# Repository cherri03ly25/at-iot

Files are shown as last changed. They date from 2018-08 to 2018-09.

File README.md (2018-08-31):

# BLE Sensor Board and Web Interface

This project defines a sensor board that broadcasts information to an IoT gateway, which then pushes the data to Azure IoT Hub. The data is then transferred to a node.js webserver that then broadcasts it to browser clients.

## Contents

* KiCAD schematics and PCB design for an nRF52840-powered sensor board
* source code for the nRF52840, required for it to send data to an IoT gateway utilizing BLE beacons
* source code for a node.js webserver capable of receiving data from Azure IoT Hub and broadcasting it to the users of a website
* the documentation for all of the above, instructions

## Installation Instructions

All parts of this project (webserver, firmware and KiCAD schematics) come with installation instructions. They can be found in their respective directories, in the INSTALL file.

## Licensing

See LICENSE.

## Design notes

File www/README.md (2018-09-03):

# Web Interface

## Supported Browsers

Browser | Version
-------:|:------
Mozilla Firefox | 60.0+
Google Chrome | 67.0+
Safari | 11.0+
Microsoft Edge | N/A

## Installation Instructions

Due to the short amount of time available for this project, server installation is only documented for linux machines with the Aptitude package manager installed.

### Steps

1. Install node.js, and optionally npm and pm2.
2. Install socket.io and express. (This can be done by running `npm install` in `./node.js` if npm was installed)
3. Tweak `node.js/config.json` to your liking.
4. Run server with `node node.js/index.js` or `pm2 start node.js/index.js`
5. Navigate to [http://localhost:3000/atsb] if using the default settings.

### Dependencies

Dependency | Required | Recommended | Version | Install Command
----------:|:--------:|:-----------:|:-------:|:----------------
`node.js` 	| x | x | v8.10.0 	| `sudo apt install nodejs`
`npm` 		|   | x | 3.5.2 	| `sudo apt install npm`
`pm2` 		|   | x | 2.10.4 	| `sudo npm install -g pm2`
`socket.io` 	| x | x | 2.1.1 	| `npm install socket.io`
`express`	| x | x | 4.16.3 | `npm install express`

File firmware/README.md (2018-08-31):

After cloning the git the submodules need to be updated using the command: 
'git submodule update --init'
to get the necessary sensor APIs.
### Packet Format
| Field | Size (in bytes) | Fixed Value | Description |
|:-----:|:----:|:---:|:---:|
| **Fixed Header** |
| Length | 1 | 0x1E |
| Type | 1 | 0xFF |
| Company ID | 2 | 0xFFFF | Bluetooth company ID |
| **Payload** |
| CTR | 4 | | Incrementing counter to improve security
| DATA1 | 4 | | The data
| TYP1 | 2 | | The data type
| DATA2 | 4 | | The data
| TYP2 | 2 | | The data type
| HASH | 11 | | A hash of the encrypted data
												
* modified to have max 27 bytes of user payload
* modified sdk_config.h and Makefile to run ble-twi-aes
* created encrypt.h and encrypt.c for data encryption
* created drivers for AES,I2C,BME280,APDS9960,sensors.h etc.
* refactoring
											
### Update:
* run beacon at low power mode
* added radio_notification SWI interrupt (need removing nrf_error.h in  sdk/components/drivers_nrf/nrf_soc_nosd)
* modified payload
* successfully uploaded codes to the custom board
* extract and give the path to sdk in Makefile
* replace Makefile.posix in sdk/components/toolchain/gcc with one in config/
* Jlink debugging at different terminals:

$ JLinkExe -if swd -device nrf52 -AutoConnect 1 -speed 4000

$ JLinkRTTClient

### Instructions of setting up development environment:

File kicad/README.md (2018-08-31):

# README

## Prerequisites

To view or edit pcb design files you need to use KiCad v5.0 program. 

Required libraries you can get from SnapEDA: https://www.snapeda.com/

Needed parts:

* Rigado BMD-340
* LP5907MFX-3.3_NOPB
* BMI055
* APDS-9960 

## Installing KiCAD
 
You can get KiCad for your operating system from http://kicad-pcb.org/ website.

1. Install KiCAD
2. Run KiCAD
3. Use recommended library settings
4. Get project from GitHub
5. Open .pro file from project folder with KiCAD
6. Now you can modify schema/layout with eeschema/pcbnew
7. To import symbol libraries go in Eeschema to "Preferences->Manage Symbol Libraries" and add.
8. To import footprint libraries go in Pcbnew to "Preferences->Manage Footprint Libraries" and add.

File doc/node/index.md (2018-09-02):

# Data Aggregation Server

## Installation

Refer to the [README](../../www/node.js/README.md)
for the installation instructions.

## Data Format

After parsing the data, the server stores a single reading as an object
in the below format.
Additional properties may be added.

        {
            id: "<sensor id>@<device mac>",
            value: <number>,
            time: <ms since epoch>
        }

## Command Line Interface

*This section details features that are not yet fully implemented.*

The server CLI can be enabled by calling `atsb.cliEnabled(true)`
in the server code. The included example has the CLI enabled
by default. Run `help` in the CLI for more information
about the available commands.

## Server-Side Events

The server emits a variety of events that can be caught by using `atsb.on(event, callback)`.
Below, a variety of events emitted by the server are detailed, along with when and where
the events are emitted, and what arguments they pass to the callback.

Event 		| Emitted by  | Arguments | Description 
:-----------|:------------|:----------|:----------------
`Info` 		| all modules | type, str, ...args | See below.
`Warning`	| all modules | type, str, ...args | See below.
`Error`		| all modules | type, str, ...args | See below.

The next few sections detail the various types of `Info`, `Warning` and `Error`
events. It should be noted that the `type` and `str` arguments are omitted in
those sections to reduce redundancy, but they *will* be passed to any callback
listening to any of the three events.

### Info Events

Emitted when the server does something of potential interest, e.g. adds a new device.
The `type` argument is a short name for what happened, and the following `str` gives
a more detailed account, suitable for logging.

Type | Emitted by | Arguments | Description
:----|:-----------|:----------|:------------------
`ClientConnected` | `atsb.js` | socket, user | Emitted when a user connects to the server. `user` is an object describing their credentials and permissions.
`ClientDisconnected` | `atsb.js` | socket, user | Emitted when a user disconnects. Otherwise same as `ClientConnected`.
`DeviceAdded` | `device.js` | device | Emitted when the server registers a new device.
`DeviceUpdated` | `device.js` | device, propertyName, propertyValue | Emitted when the server changes device information - e.g. adds new sensors, or changes the name.
`MessageParsed` | `atsb.js` | msgId, nParsed | Emitted when the server parses a message from a beacon. `msgId` is an 8-character identifier to help tracking messages, and `nParsed` is the number of readings parsed from the message.
`PostReceived` | `atsb.js` | msgId | Emitted when the server receives a POST request
`StreamedData` | `atsb.js` | msgId | Emitted when the server streams the data from a POST request

### Warning Events

Emitted when the server does something that potentially requires attention.
The `type` argument is a short name for what happened, and the following `str` gives
a more detailed account, suitable for logging.

Type | Emitted by | Arguments | Description
:----|:-----------|:----------|:------------------
`CounterValidationWarning` | `parser.js` | msgId, mac, msg | Emitted when a message with an invalid counter is received.
`HMACValidationWarning` | `parser.js` | msgId, mac, msg | Emitted if HMAC validation fails.
`NoParserOutputWarning` | `atsb.js` | msgId, msg, parser | Emitted if a parser produces no output.
`UnknownDeviceWarning` | `parser.js` | msgId, mac, msg | Emitted if data was received from an unknown device.
`UserAuthWarning` | `atsb.js` | socket, user | Emitted when a user lacks the permissions to view the stream.

### Error Events

Emitted when the server does something that almost certainly requires attention.
The `type` argument is a short name for what happened, and the following `str` gives
a more detailed account, suitable for logging.

Type | Emitted by | Arguments | Description
:----|:-----------|:----------|:------------------
`ParserNotFoundError` | `atsb.js` | msgId, msg | Emitted if no parser was found for the message.

## Client-Side Events

If desired, the visualization client may be rewritten. This can be done by
connecting to the appropriate Socket.IO namespace, and by handling and emitting 
the events described below. If the event is not marked as 'Implemented', it is
not yet supported by the server.

Upon connecting to the server, the client receives an object describing its
permissions. Refer to the [Permissions Module](./permissions.md) for more information.
The client can choose to ignore these, but the server will enforce them.

### Events Emitted by Server

Event | Implemented | Arguments | Description
:----|:----------|:----------|:------------------
`Data`  | x | data | Data. Either a single data point, or an `Array`. The data matches the [Data Format](#data-format)
`DeviceAdded`| x | devInfo | Emitted when the server registers a new device. `devInfo` is an object describing the device.
`DeviceList` | x | devInfoList | Emitted upon list request or when connecting to the server. `devInfoList` contains all device info objects.
`DeviceUpdated` | x | devInfo | Emitted when the server updates a device. `devInfo` is the updated device description.

### Events Emitted by Client

Event | Implemented | Arguments | Description
:----|:----------|:----------|:------------------
`ListDevices` | x | Used to request the list of devices.
`Subscribe` | x | rooms | `rooms` should be an `Array` of sensor identifiers. This event indicates to the server that the client wants the associated data.
`Unsubscribe` | x | rooms | This event can be used to undo `Subscribe`.
`RequestData` | | requests | Used to request data from a certain interval and sensor from the server. `requests` is an `Array` of objects: `{id:<sensor id>, start:<time1>, end:<time2>}`
`ChangeDevice`| | mac, property, value | Used to update a property of a device, e.g. rename it or edit its key.
`AddDevice` | | mac, key, name | Used to create a new device.

## Customizing the Server

There are two primary methods to customizing the server to suit
your needs: editing the JSON configs or by overriding functions or modules.

### config.json

*Some of the features described in this section are not fully described.*

Options available are:

Option | Values | Default | Description
:------|:-------|:-----------------
`urlPrefix` | String | "/atsb" | Sets the prefix to all related URLs, including the endpoints and static files.
`urlEndpoint` | String | "/endpoint/webhook" | Sets the endpoint. To use URL authentication, include `:auth` in the URL.
`namespace` | String | "atsb" | The name of the Socket.IO namespace.
`defaultParser` | String, `null` | "./parser.js" | The name of the parser to load on initialization. Set to `null` for none.
`logging` | | | Various options for logging
`logging.enabled` | boolean | `true` | Enable or disable logging
`logging.events` | Array | `["Warning", "Error"]` | A list of all the events to log. "All" for all events, "Info", "Warning" or "Error" for all events of that category.
`logging.prefix` | String | "\[ATSB\] <$TIME> $TYPE: " | A prefix to prepend to all logged events. '$TIME' is replaced with current time (hh:mm:ss) and '$TYPE' with the event type.
`logging.postfix` | String | "" | A postfix to append to logged events. Works like `logging.prefix`.
`storage` | | | Various options for the default storage module
`storage.prefix` | String | "$DIRNAME/var/atsb" | A prefix to append to all file paths (except config). '$DIRNAME' is replaced with the `__dirname` variable.
`storage.data` | String | "/data/$YYYY/$MM/$DD/$hh$mm" | The file(s) to store collected data in. The variables ($YYYY, $MM, etc.) are replaced with the appropriate time from the data timestamp(s).
`storage.exitSave` | boolean | `true` | Whether the server should save changed configurations on exit. If disabled, calling `atsb.save()` does the same.
`storage.devices` | String | "devices.json" | The file to store device configurations in.
`storage.sensors` | String | "sensors.json" | The file to store sensor configurations in for the default parser.
`storage.users` | String | "users.json" | The file to store users, their permissions and login credentials in.
`storage.compression` | boolean | `true` | Whether files should be compressed.
`storage.encryption` | | | Various options for encrypting files
`storage.encryption.enabled` | boolean | true | Whether to encrypt/decrypt files.
`storage.encryption.keyMethod` | String | "stdin" | How to retrieve the key. "stdin" queries the key from `stdin` on startup, "config" requires the key to be defined in the config file (very insecure!), "file" retrieves the key from a file (equally insecure).
`storage.encryption.key` | String, `null` | `null` | If `storage.encryption.keyMethod` is set to "config", this option sets the key. It should be a hex-encoded string.
`storage.encryption.algorithm` | String | "aes-256" | The encryption algorithm for the module. Must be supported by the `crypto` module.

### Storage

The API for the storage module is not yet done, so this section is left empty

### Custom Parsers

The server software supports addition of new parsers for user-defined protocols.
This is done by creating a new object that has the public member functions 
`canParse()` and `parse()` defined as below. If desired, the parser may also
implement the `info()` function.

If desired, the default parser can be disabled by setting `defaultParser` in
`config.json` to `null`, or replaced by setting it to refer to a new file
(not recommended).

#### canParse(msg)

* The function must take a single argument, the message.
* It must determine whether the message is a valid input for `parse()`
* It must return `true` if the message is valid input, and `false` otherwise

#### parse(msg, msgId)

* The function is passed two arguments: the message, and the message identifier.
* It must parse the message, and return an `Array` containing data objects. 
* The parsed data objects *must* follow the [Data Format](#data-format).
* The function should return an empty set (`[]`) if the message contained no readings.
* The function should return `null` if the parser failed due to invalid message.
* The function *may* call `update()` on the associated `Device`(s)
* The function *may* call `log()` on the associated `Device`(s).
The default parser logs the following statistics: 
`AllMessages`, `ValidMessages`, `SkippedMessages`, `InvalidCTRs`, `InvalidHMACs`
* The `msgId` parameter can safely be ignored
* The implementation can safely assume that `canParse()` returned
true for the message.

#### info(...args)

*This section details features that are not made use of in the current version*

* The function is called when the user uses the `parser info <parser>` command.
* Any arguments after `<parser>` are passed to the function.
* The function should return either an `Array` of `string`s or a `string`.
* The return value is printed in console.
* If the returned value was an `Array`, `join("\n")` is called on it first.

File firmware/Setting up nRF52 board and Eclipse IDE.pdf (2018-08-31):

## Setting up development environment

Notes: executable files can be installed graphically or by command lines

### 1. GNU make

$ sudo apt install build-essential checkinstall

### 2. GNU toolchain for ARM Cortex-M

Download and install the GNU ARM Toolchain package for linux-64 (https://developer.arm.com/open-source/gnu-toolchain/gnu-rm/downloads) $ sudo apt install unzip
$ tar xf gcc-arm-none-eabi-7-2017-q4-major-linux.tar.bz2
// may need gcc_multilib
$ sudo apt install gcc-multilib
// add the location to the path temporarily when executing locally in a terminal:
$ export PATH=$PATH: $(HOME)/.../.../gcc-arm-none-eabi-7-2017-q4-major/bin $ echo $PATH

### 3. SEGGER J_Link

Download and install the Segger JLink package for linux-DEB-64 (https://www.segger.com/downloads/jlink/#J-LinkSoftwareAndDocumentationPack)
$ sudo dpkg -i JLink_Linux_V632g_x86_64.deb //check exe file "jlink*" under usr/bin

### 4. nRF5_SDK

Download and unzip the nRF52-SDK zip package (http://infocenter.nordicsemi.com/index.jsp)
//To do make, need to source GNU ARM
nRF52_SDK >>components >> toolchain >> gcc >> Makefile.posix
GNU_INSTALL_ROOT := $(HOME)/.../.../gcc-arm-none-eabi-7-2017-q4-major/bin/ yGNU_VERSION := 7.2.1
GNU_PREFIX := arm-none-eabi

### 5. nRF5x-Command-Line-Tools

Download the nRF5x Tools Linux64 (https://www.nordicsemi.com/eng/nordic/Products/nRF52840/nRF5x-Command-Line-Tools-Linux64/58852) (see p.10) (http://www.farnell.com/datasheets/2577979.pdf) $ gedit ~/.bashrc
export PATH=$PATH:~/.../.../nRF5x-Command-Line-Tools/nrfjprog export PATH=$PATH:~/.../.../nRF5x-Command-Line-Tools/mergehex

### 6. Reset MCU interface

JLINK interface is set as default interface for the dev kit and chosen to be used in this project. Other MCU interface can be used, for example DAPLINK interface.
JLINK interface: Download .bin file for JLINK interface software (http://www.nordicsemi.com/eng/nordic/Products/nRF52-DK/nRF5x-OB-JLink-IF/52275) from: http://www.nordicsemi.com/eng/Products/nRF52840-DK#Downloads
DAPLINK interface: Download .bin file for DAPLINK interface software (https://armmbed.github.io/DAPLink/?board=Nordic-nRF52-DK) from os.mbed.com (https://os.mbed.com/platforms/Nordic-nRF52840-DK/)

- Press boot/reset button while turning power switch from OFF to ON -> BOOTLOADER mode
- Copy the downloaded .bin file into devboard and wait until LED5 fast flashing
- Press boot/reset button while turning power switch from OFF to ON -> MCU interface (JLINK/DAPLINK etc.) is reset.

### 7. Run demo with GCC and command tools (JLink interface)

Change directory to ~/.../.../sdk/examples/peripheral/blinky/pca10056/blank/armgcc/
//do make, _build folder is created
$ make

/*1. run with nrfjprog*/
//erase target
$ nrfjprog --family nRF52 -e
//load FW image to target
$ nrfjprog --family nRF52 --program _build/nrf52840_xxaa.hex //reset and run
$ nrfjprog --family nRF52 -r

/*2. run with JLinkExe*/
/* Open Jlink Commander from terminal in _build directory */ JLinkExe -device <nRF51/nRF52>
> erase // Optional: erase target if not already blank
> loadfile <name>.hex // loads FW
> r // Reset and halt
> g // Run
> q // Exit

/*3. directly copy example .hex file into target via USB*/

### 8. Program target with os.mbed.com/compiler

- Target device: nRF52-DK
- Import demo project nRF52840-Preview-DK-blinky
- Use mbed.h library for high level programming
- Code and compile to create application .hex file
- Copy the .hex file to the target and wait until the JLINK/DAPLINK interface disappears and reappears
- Press boot/reset button to start running the application
Good reference -> import BLE project: mbed-os-example-client-BLE-NRF52_DK (https://github.com/andcor02/mbed-os-NRF52_DK-Gateway)

### 9. Setting up Eclipse IDE

***Download and install Eclipse***

- Download and unzip eclipse package (newest version of Eclipse Oxygen linux 64 bit): http://www.eclipse.org/downloads/
- Double click on "eclipse-inst" exe file >> Eclipse IDE for C/C++ Developers >> choose directory for installation
- Double click on "eclipse" exe file >> choose directory for workspace
- Source exe file:
$ gedit ~/.bashrc
export PATH=$PATH:~/.../.../eclipse

***I nstall GNU MCU eclipse plug in*** (https://gnu-mcu-eclipse.github.io/plugins/install/)
Open eclipse in terminal or by double click on the exe file >> Help >> Eclipse Marketplace >> Find and install GNU MCU Eclipse
Required packages are:
GNU ARM C/C++ Cross Compiler
GNU ARM C/C++ Packs
GNU ARM C/C++ J-link Debugging
All packages are chosen by default.

***Install device family pack for the nRF5x serie***
Window >> Perspective >> Open Perspective >> Other >> Packs >> Open.
Click the refresh button to fetch all packs from the repositories.
Select Nordic Semiconductor in the list of vendors, and install the latest version of Device family pack. (Skip if all invalid packages!)

***Create a project***
Common Settings:
- Window >> Preference >> MCU
- >> Global ARM Toolchains Paths >> Default toolchain: GNU Tools for ARM Embedded Processors >> Build tools folder: ~/.../.../gcc-arm-none-eabi-7-2017-q4-major/bin
- >> Global Build Tools Path >> Build tools folder: ~/nRF5x-Command-Line-Tools/nrfjprog
- >> Global SEGGER J-Link Path >> Executable: JLinkGDBServerCLExe >> Folder: /opt/SEGGER/JLink (default settings)

Launch example project blinky for nrf52840: File >> New >> Project >> C/C++ >> C Project Project name: blinky
Project type: Empty Project
Toolchains: ARM cross GCC
Next all with other settings as default until the project “blinky” folder appears in Project Explorer.

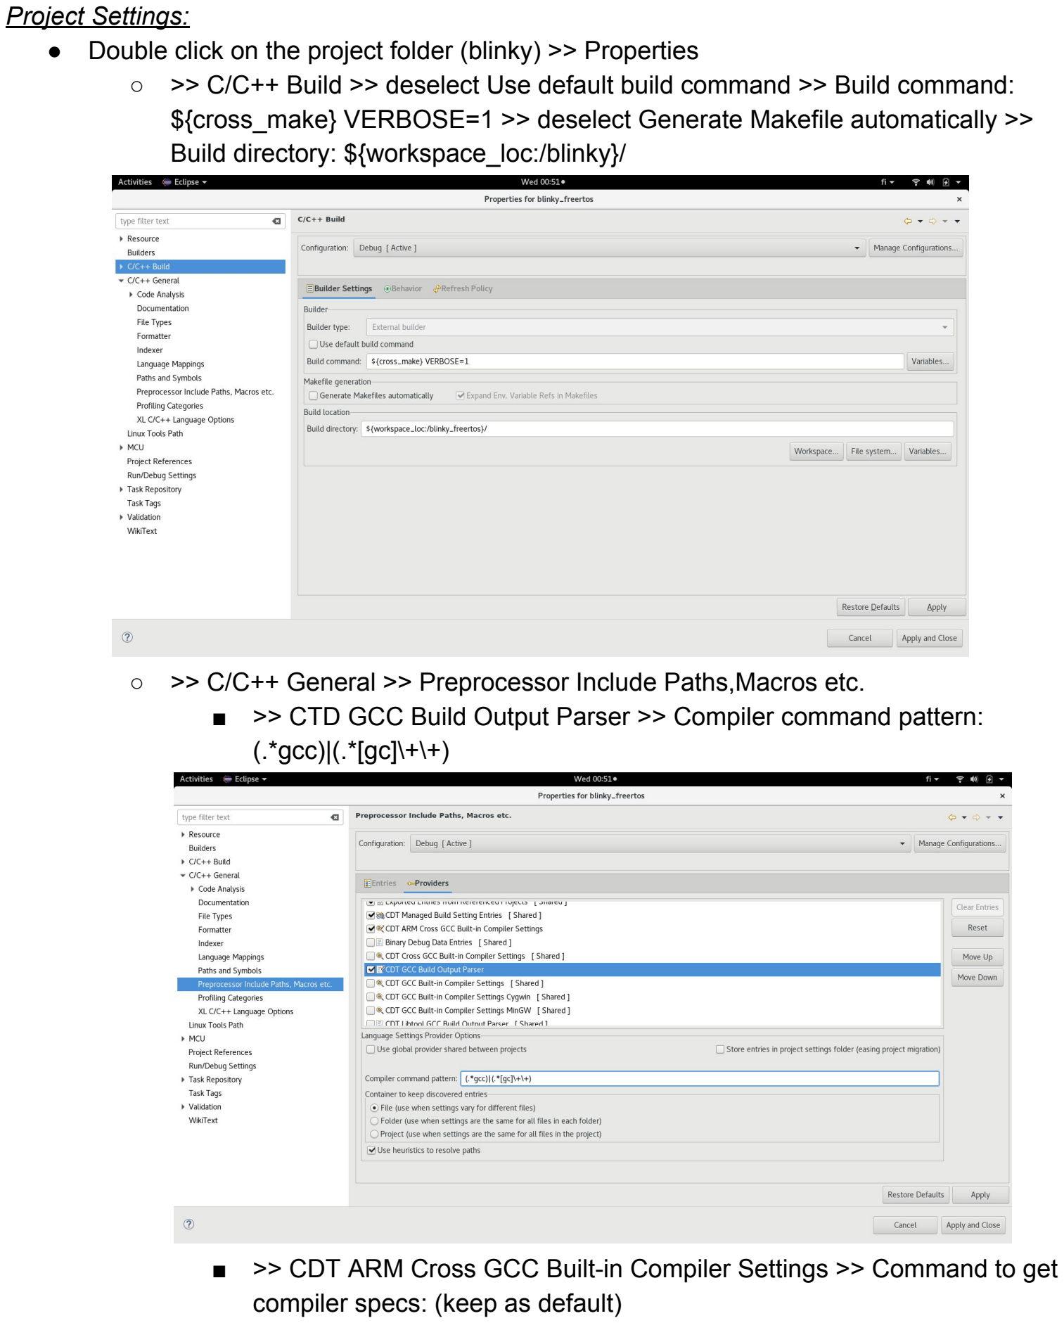
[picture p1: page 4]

Project Settings:
- Double click on the project folder (blinky) >> Properties
- >> C/C++ Build >> deselect Use default build command >> Build command: ${cross_make} VERBOSE=1 >> deselect Generate Makefile automatically >> Build directory: ${workspace_loc:/blinky}/
- >> C/C++ General >> Preprocessor Include Paths,Macros etc.
■ >> CTD GCC Build Output Parser >> Compiler command pattern: (.*gcc)|(.*[gc]\+\+)

■ >> CDT ARM Cross GCC Built-in Compiler Settings >> Command to get compiler specs: (keep as default)

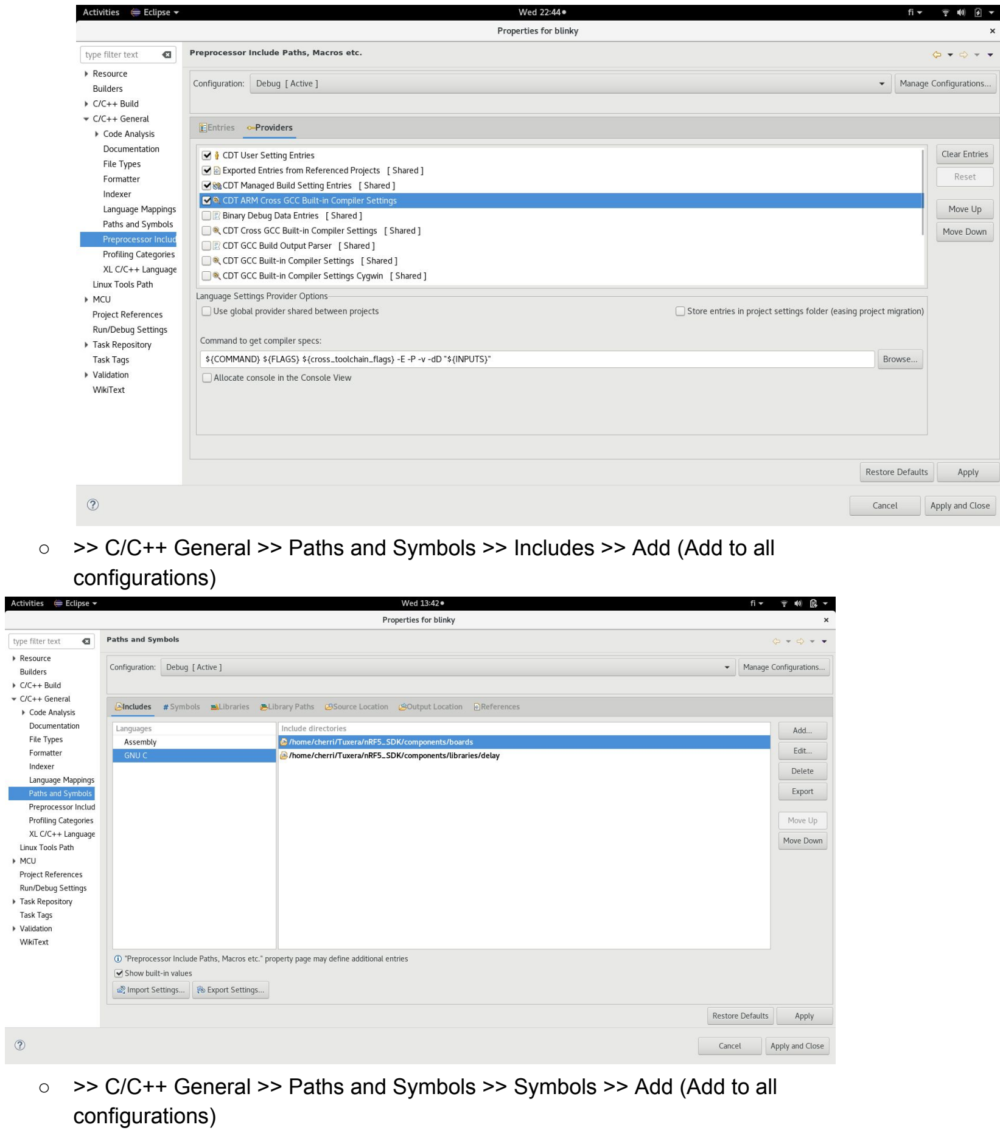
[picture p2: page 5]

- >> C/C++ General >> Paths and Symbols >> Includes >> Add (Add to all configurations)
- >> C/C++ General >> Paths and Symbols >> Symbols >> Add (Add to all configurations)

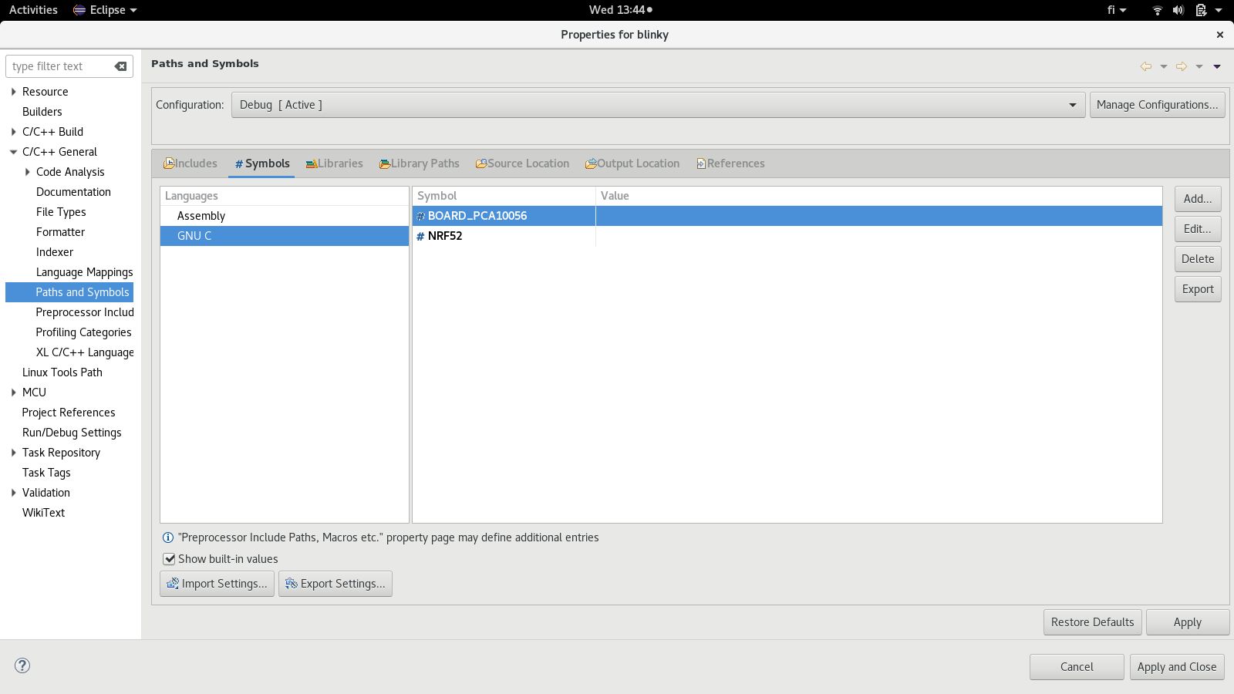
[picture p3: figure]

- Import source files from nRF5_SDK/examples/peripherical/blinky/
- main.c -> src/main.c
- pca10040/config/sdk_config.h -> inc/sdk_config.h
- pca10040/blank/armgcc/Makefile -> Makefile
- pca10040/blank/armgcc/blinky_gcc_nrf52.ld -> blinky_gcc_nrf52.ld
- Edit Makefile: (https://www.disk91.com/2017/technology/hardware/discover-nordic-semi-nrf52832/)
- SDK_ROOT := ../../../sdk | (exact location of SDK)
- PROJ_DIR := . | (location where the project is built)
- $(PROJ_DIR)/main.c \ -> $(PROJ_DIR)/src/main.c \
- $(PROJ_DIR)/ \ -> $(PROJ_DIR)/inc \
- Remove ../config \
- For CFLAGS, OPT = -O0 -g3

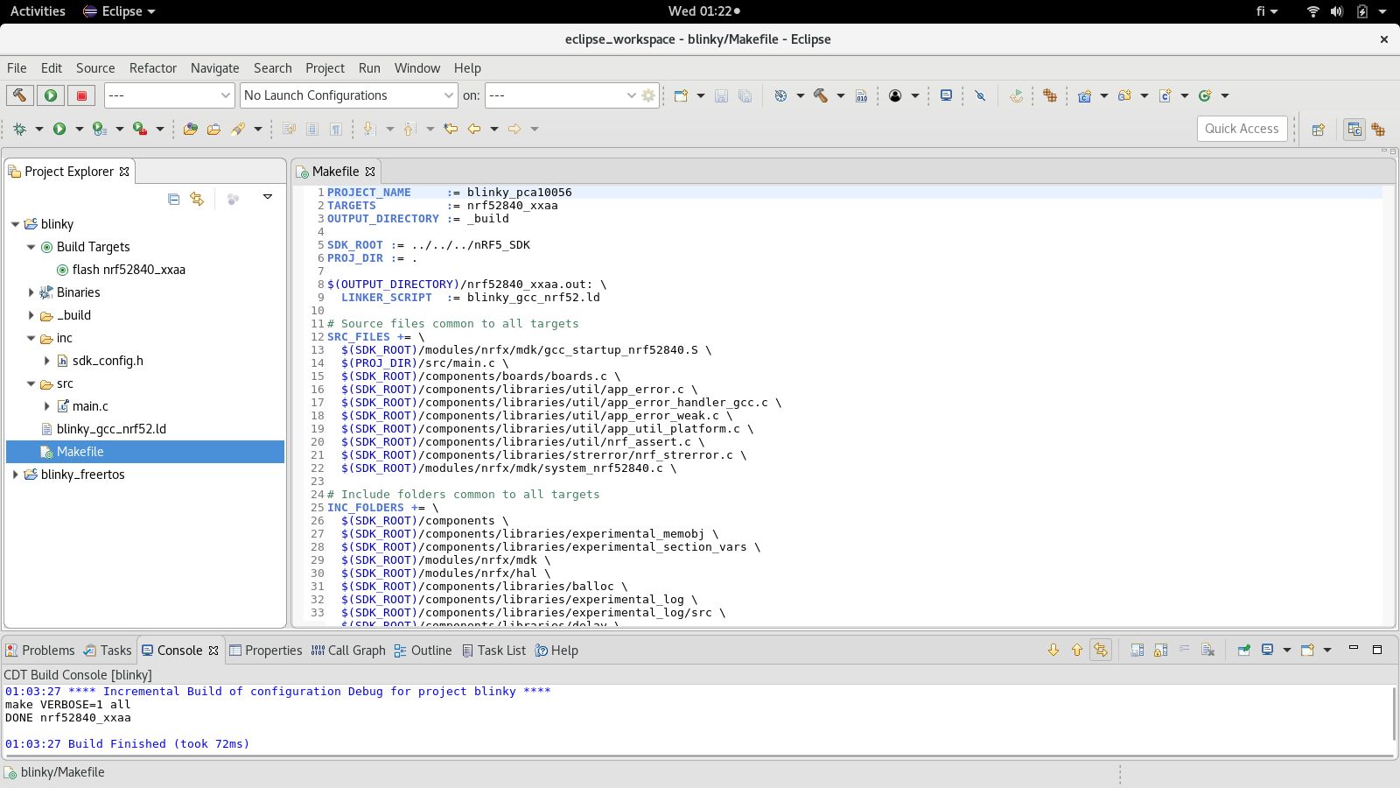
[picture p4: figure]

Build project:
Right click on the project folder >> Build Project

Build target and flash download:
Double click on the project folder >> Build Targets >> Create >> Target name: flash nrf52840_xxaa
Right click on the project folder >> Build Targets >> Create >> Target name: flash nrf52840_xxaa
Right click on the target >> Build Target

### 10. Debugging

RTT debugging at terminals:
In one terminal:
$ JLinkExe -if swd -device nrf52 -AutoConnect 1 -speed 4000 In another terminal:
$ JLinkRTTClient
Links:
https://devzone.nordicsemi.com/tutorials/b/getting-started/posts/development-with-gcc-a nd-eclipse (https://devzone.nordicsemi.com/tutorials/b/getting-started/posts/development-with-gcc-and-eclipse)
https://gnu-mcu-eclipse.github.io/debug/jlink/https://devzone.nordicsemi.com/f/nordic-q-a/14512/how-to-use-rtt-viewer-or-similar-on-gn u-linux (https://devzone.nordicsemi.com/f/nordic-q-a/14512/how-to-use-rtt-viewer-or-similar-on-gnu-linux)

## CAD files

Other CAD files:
case/case.blend

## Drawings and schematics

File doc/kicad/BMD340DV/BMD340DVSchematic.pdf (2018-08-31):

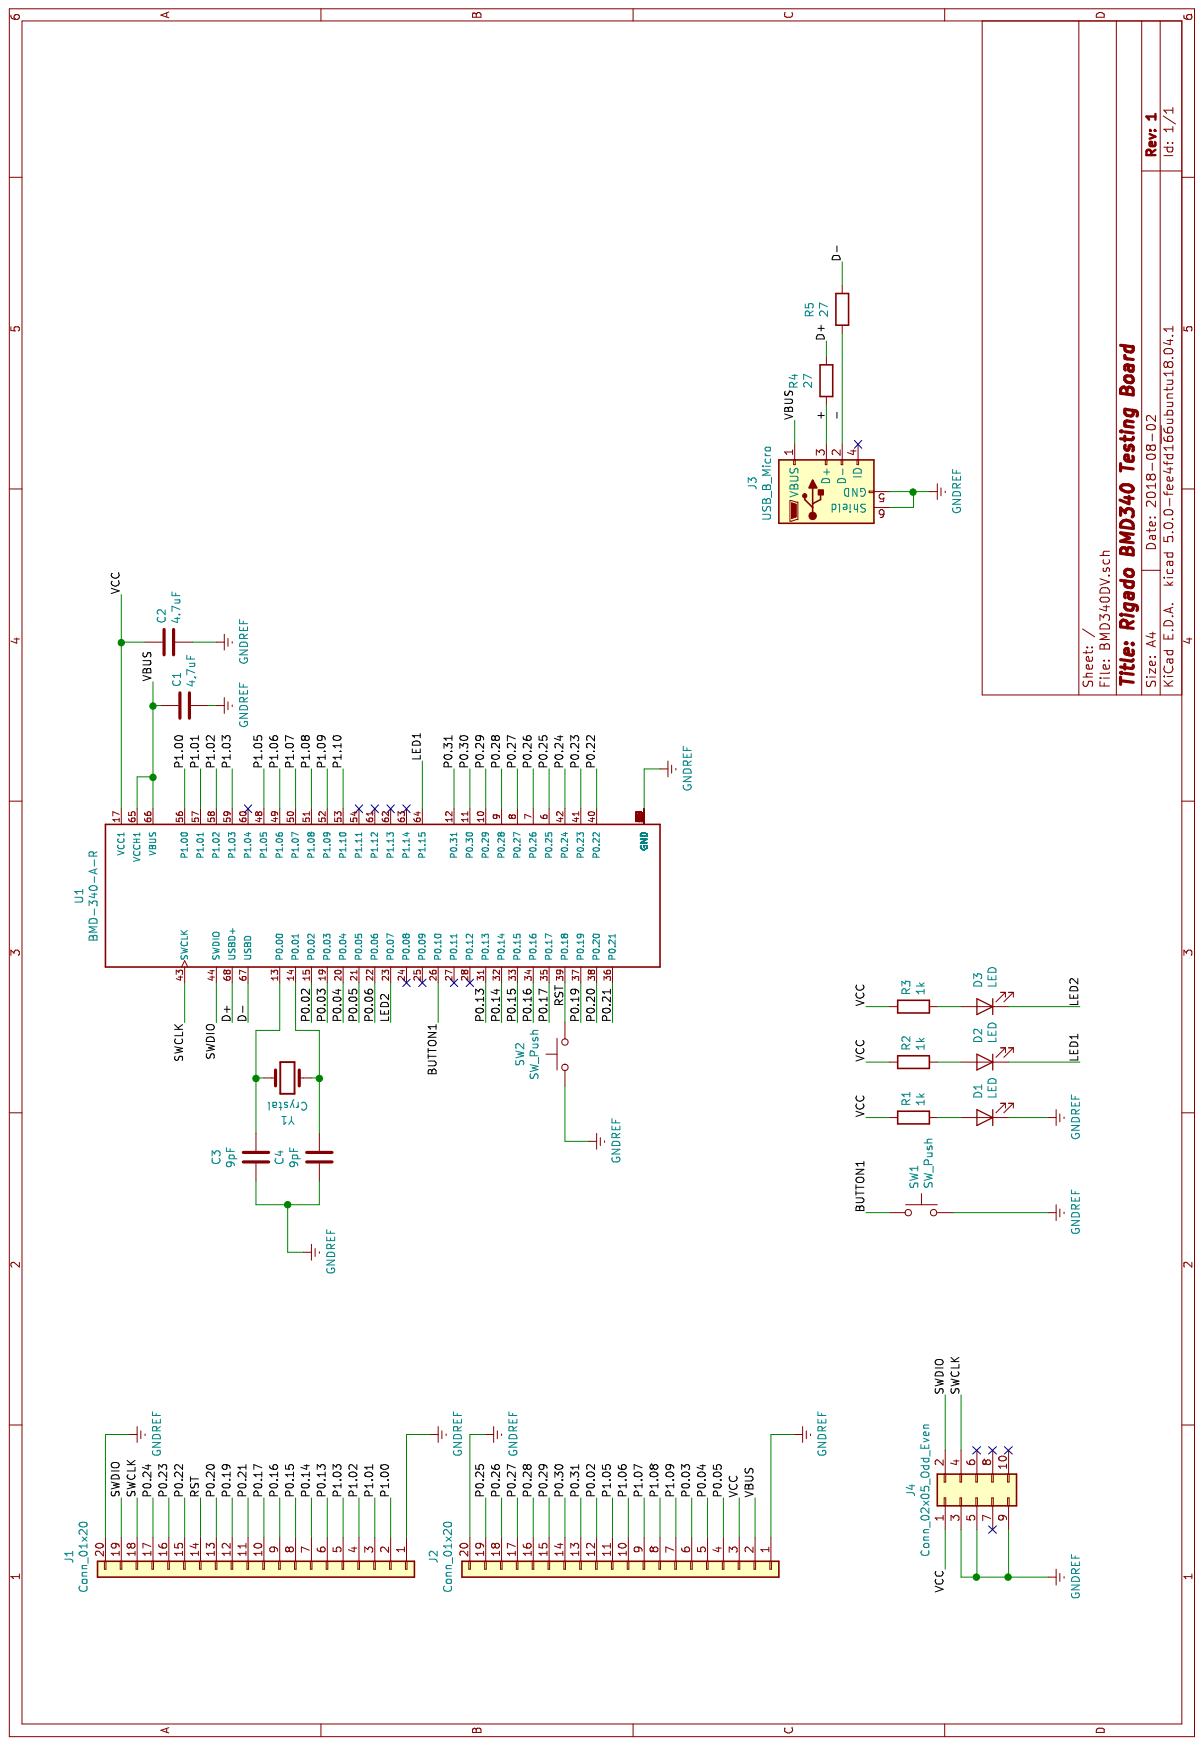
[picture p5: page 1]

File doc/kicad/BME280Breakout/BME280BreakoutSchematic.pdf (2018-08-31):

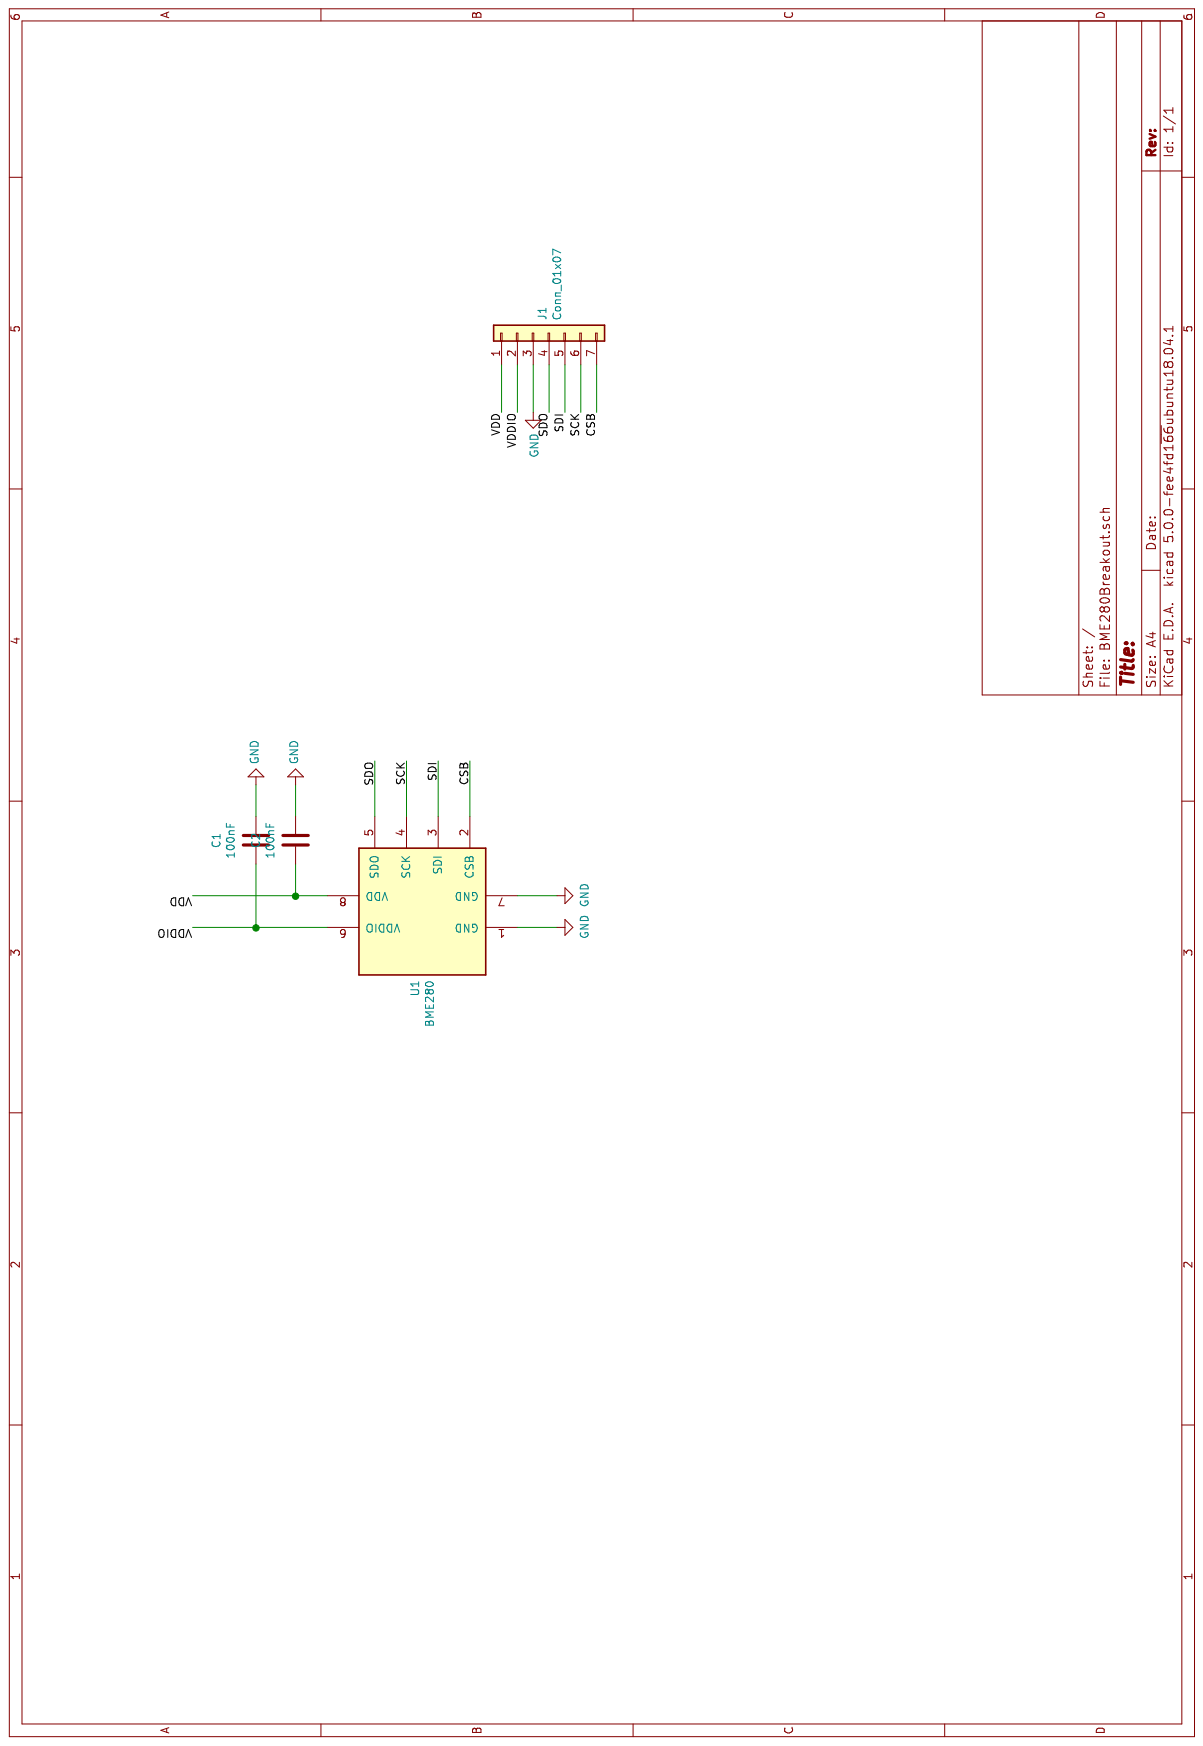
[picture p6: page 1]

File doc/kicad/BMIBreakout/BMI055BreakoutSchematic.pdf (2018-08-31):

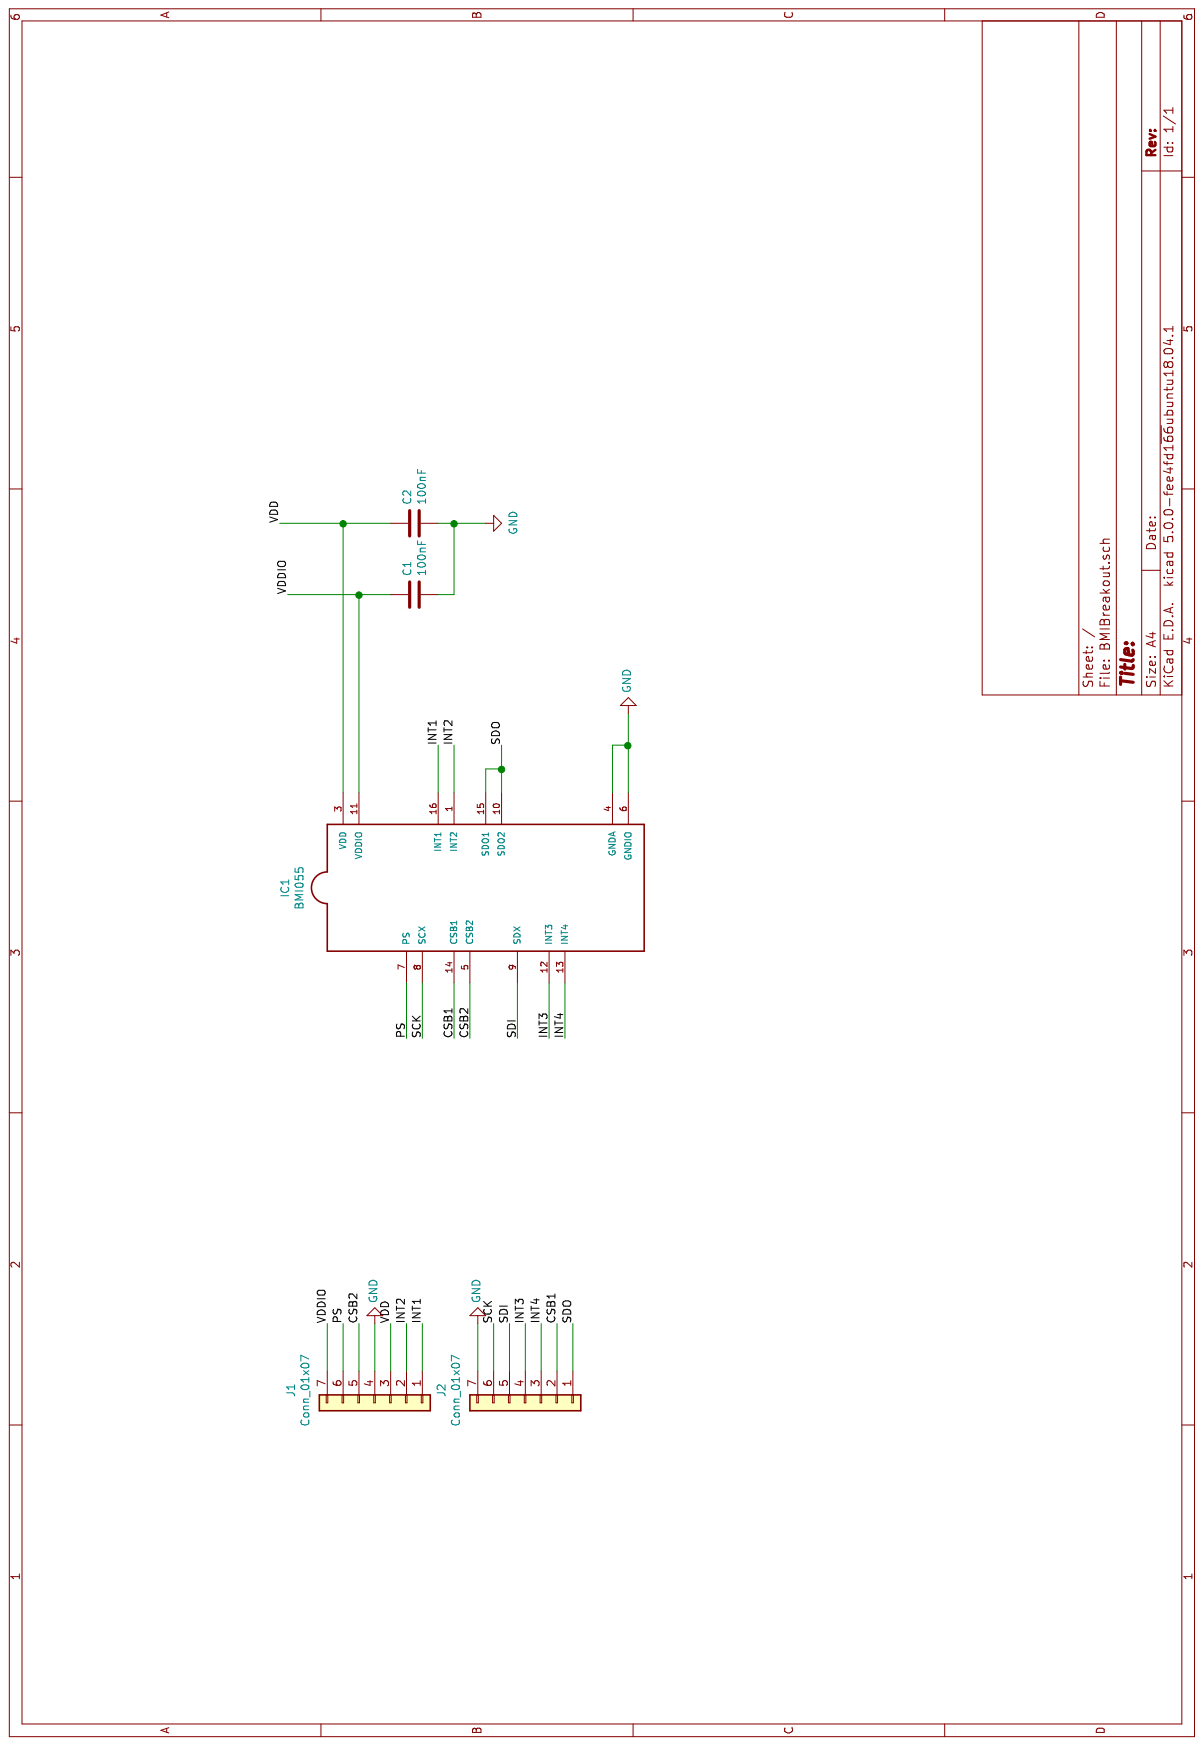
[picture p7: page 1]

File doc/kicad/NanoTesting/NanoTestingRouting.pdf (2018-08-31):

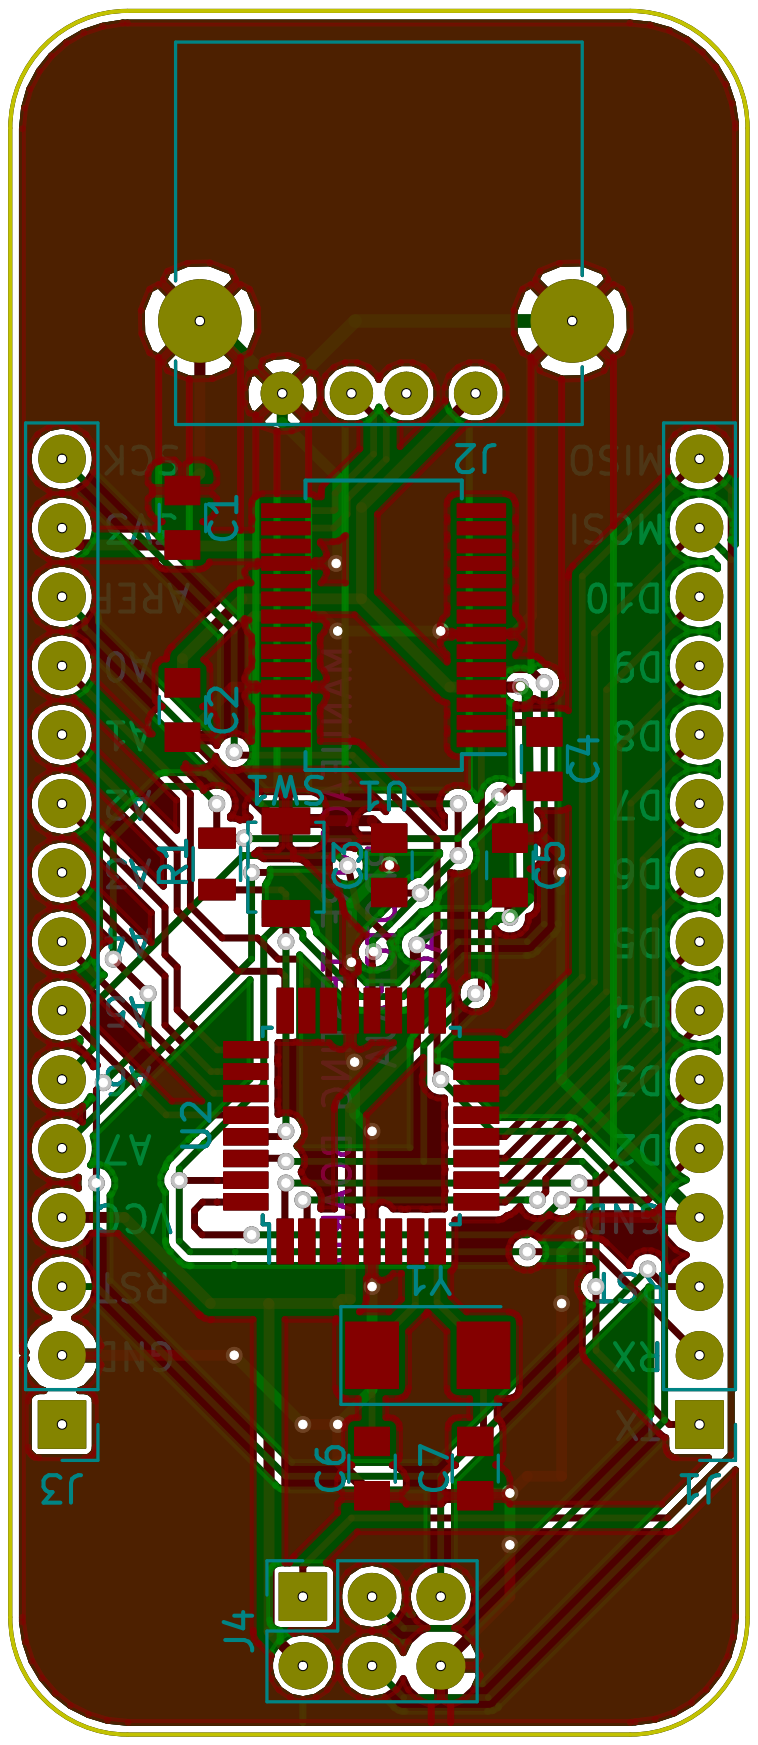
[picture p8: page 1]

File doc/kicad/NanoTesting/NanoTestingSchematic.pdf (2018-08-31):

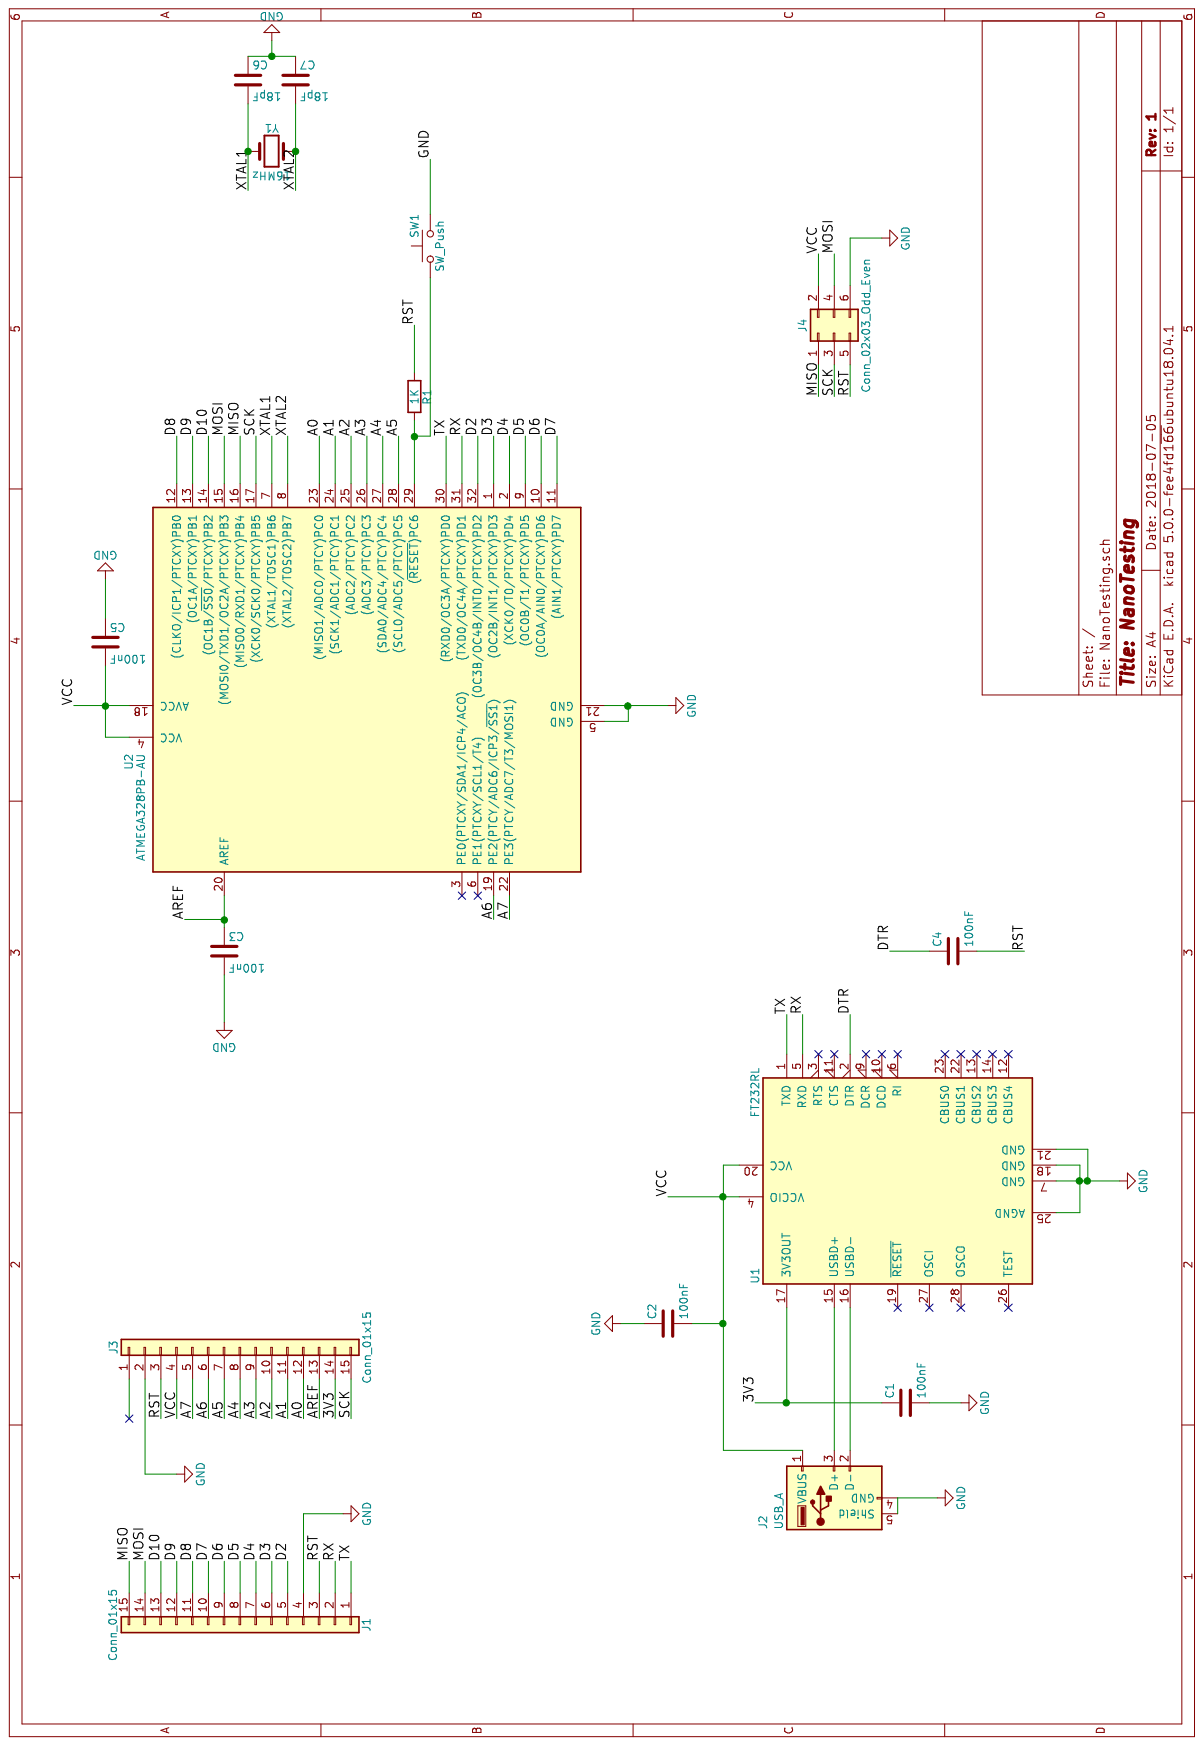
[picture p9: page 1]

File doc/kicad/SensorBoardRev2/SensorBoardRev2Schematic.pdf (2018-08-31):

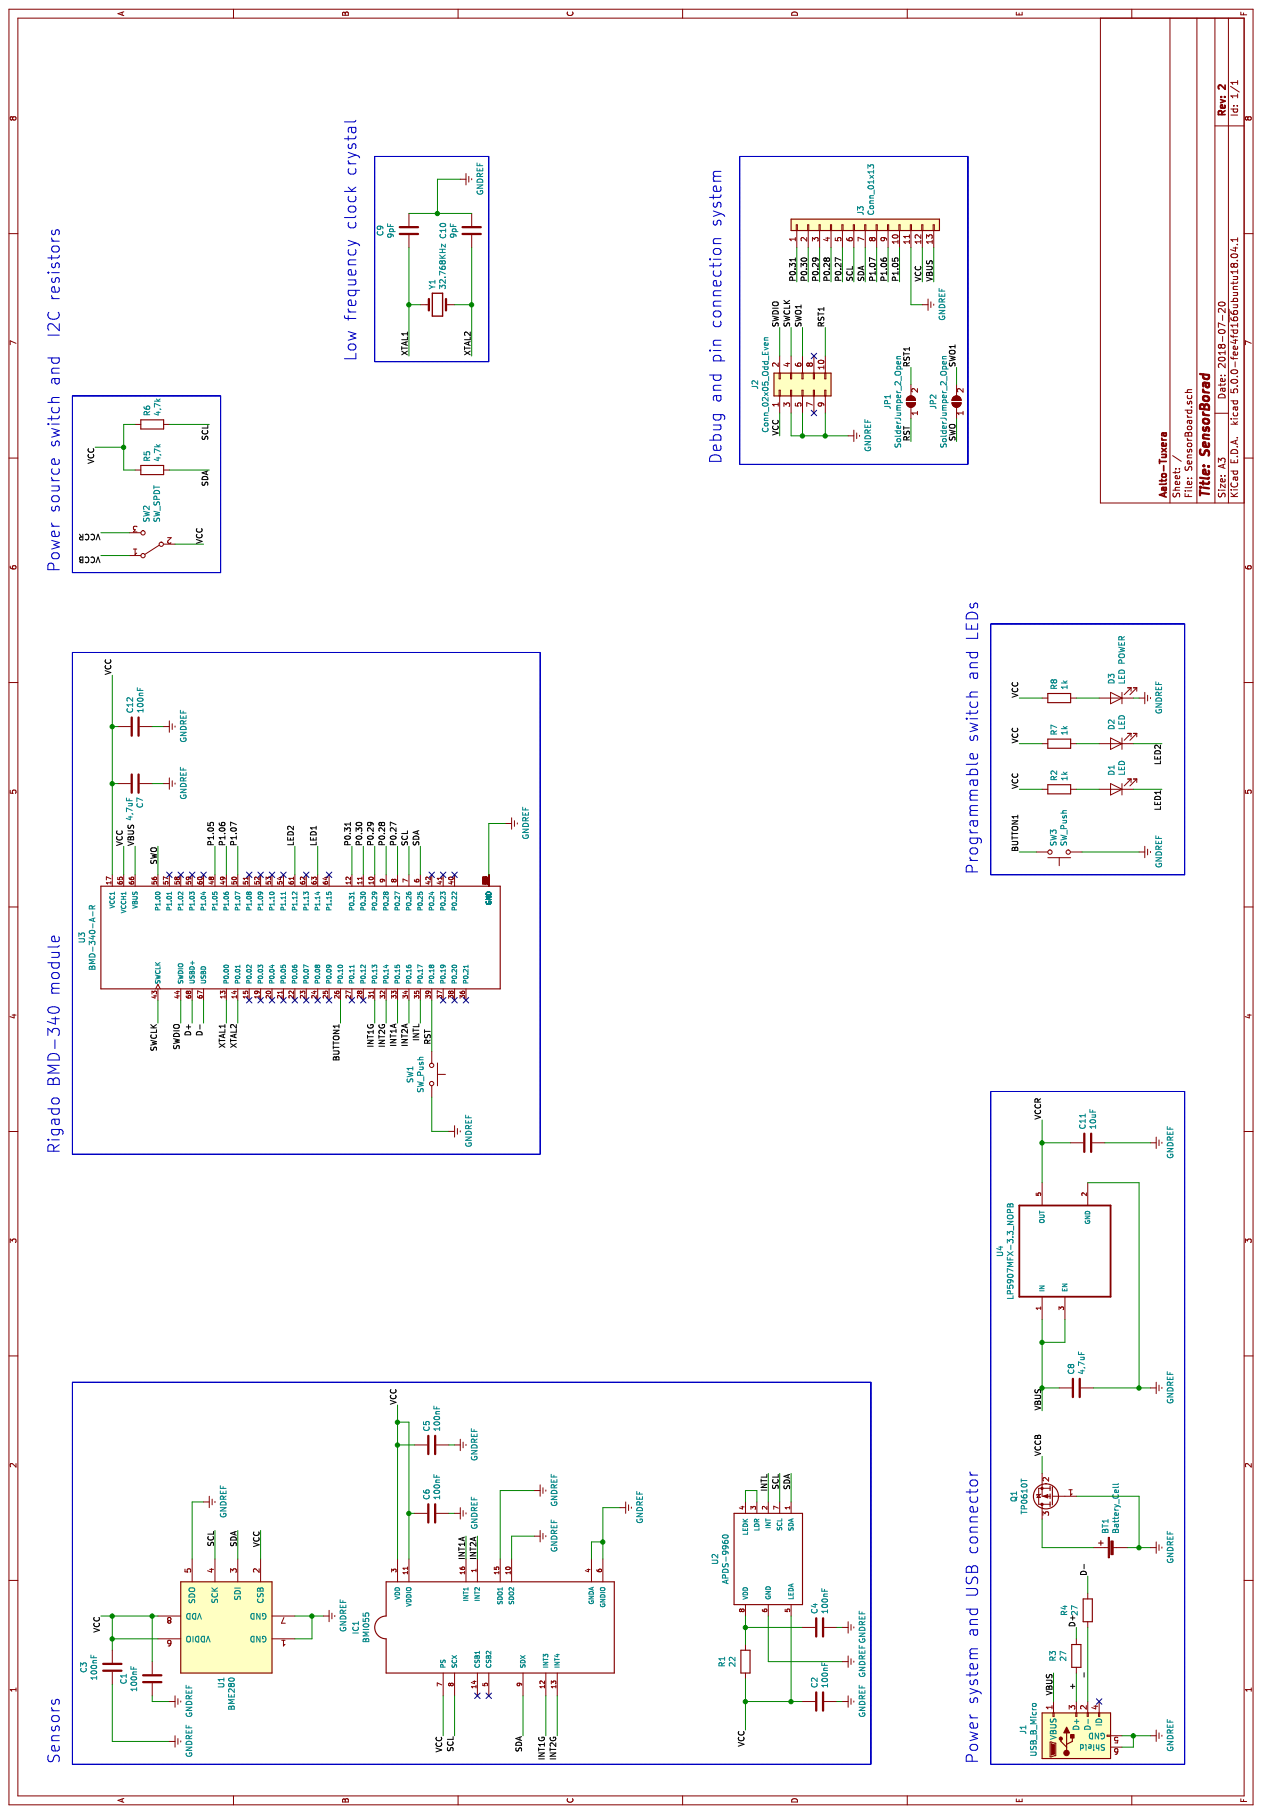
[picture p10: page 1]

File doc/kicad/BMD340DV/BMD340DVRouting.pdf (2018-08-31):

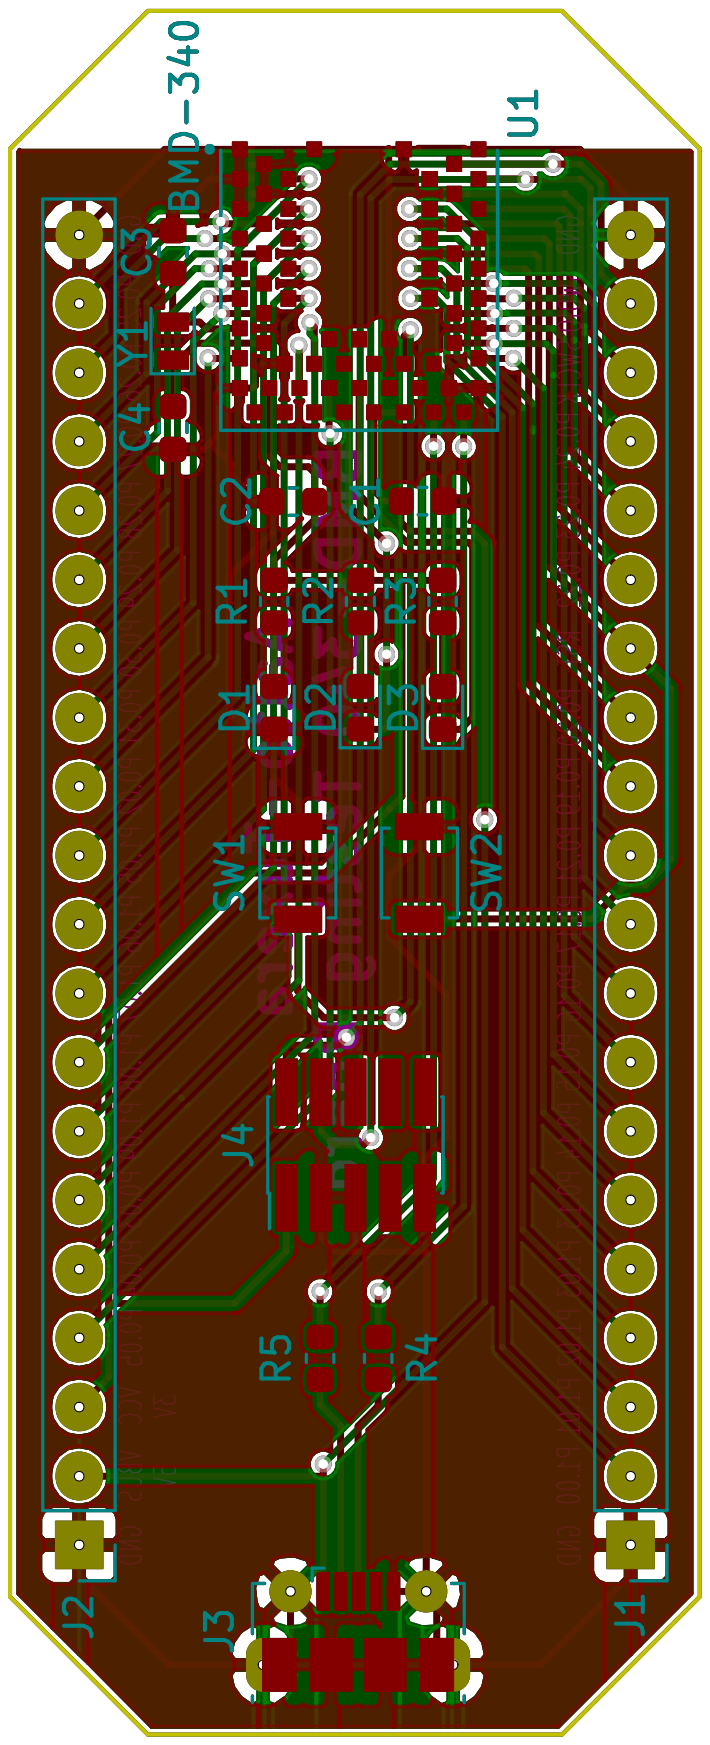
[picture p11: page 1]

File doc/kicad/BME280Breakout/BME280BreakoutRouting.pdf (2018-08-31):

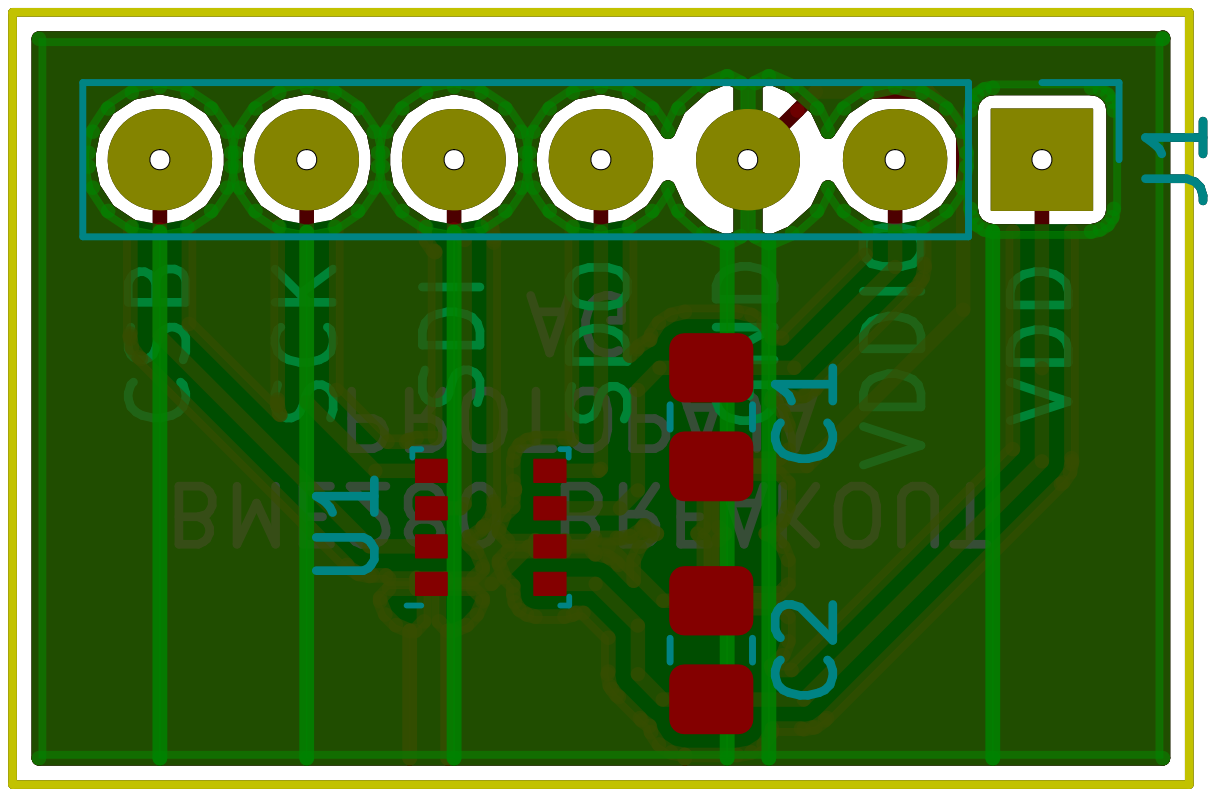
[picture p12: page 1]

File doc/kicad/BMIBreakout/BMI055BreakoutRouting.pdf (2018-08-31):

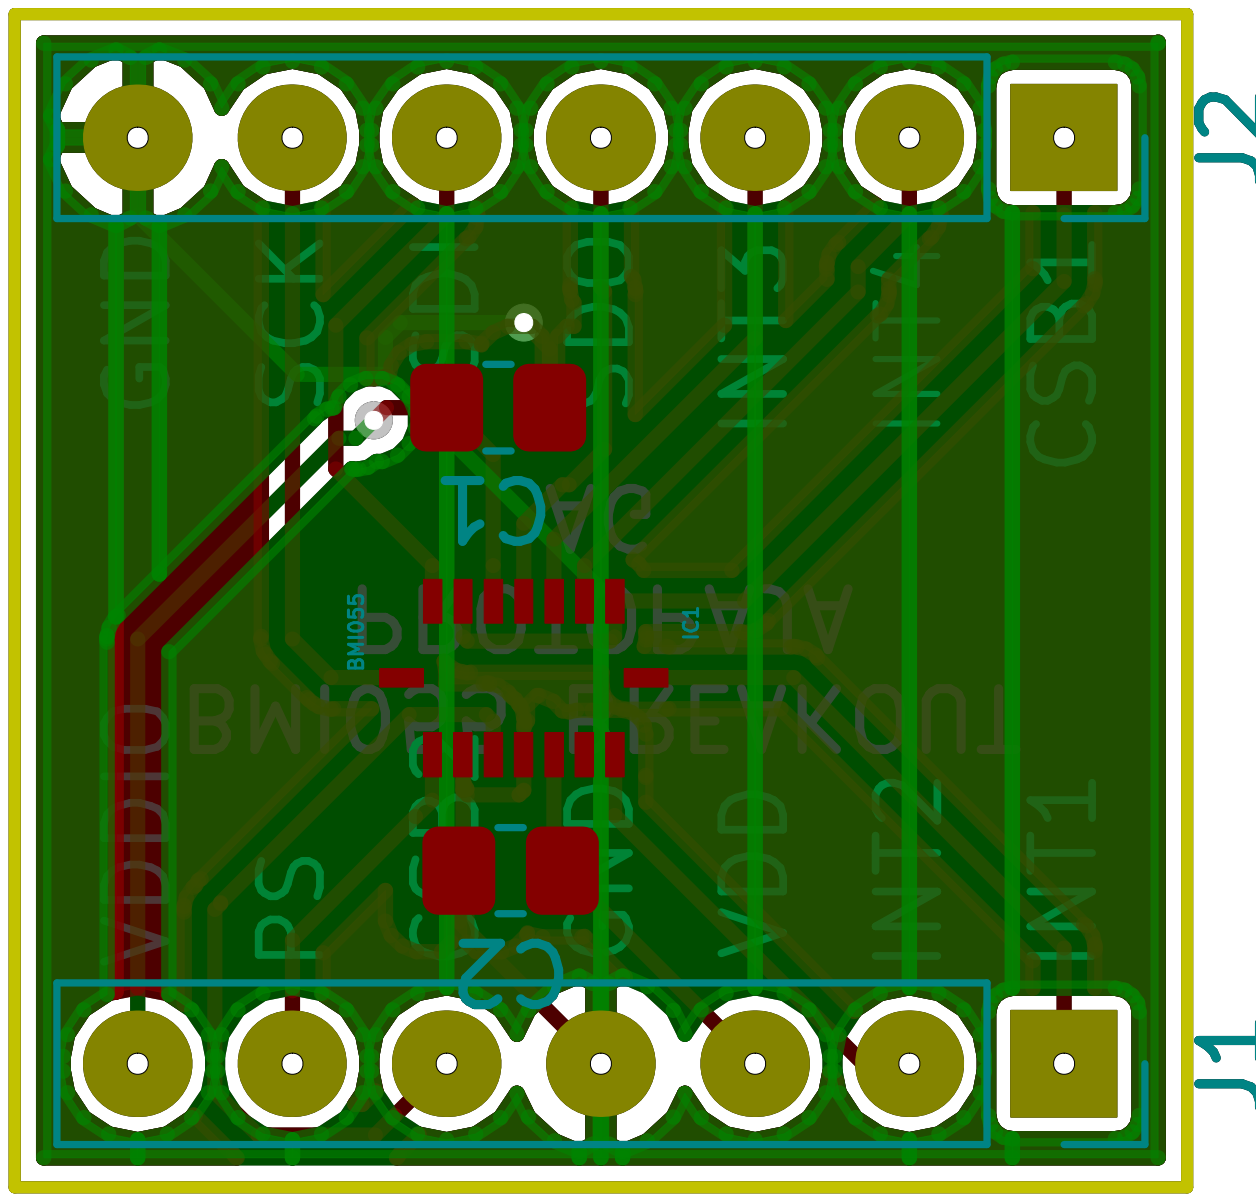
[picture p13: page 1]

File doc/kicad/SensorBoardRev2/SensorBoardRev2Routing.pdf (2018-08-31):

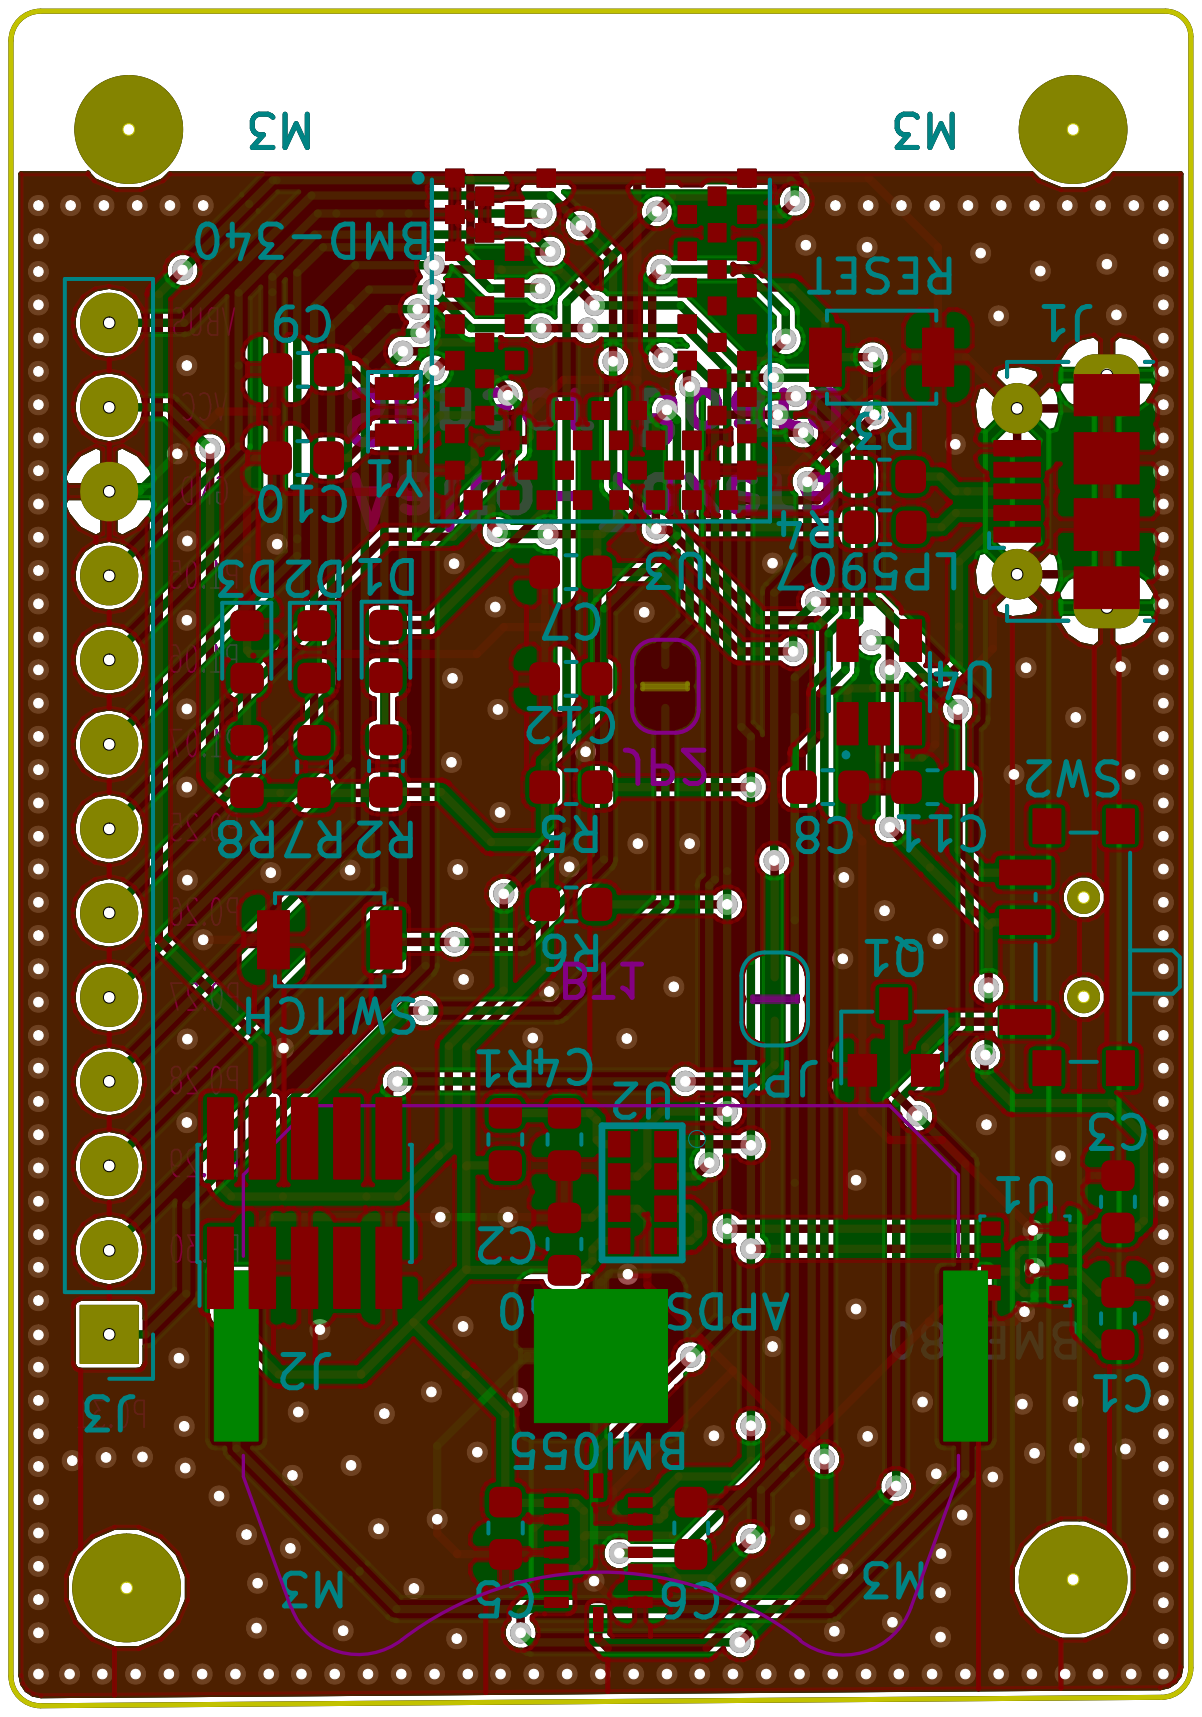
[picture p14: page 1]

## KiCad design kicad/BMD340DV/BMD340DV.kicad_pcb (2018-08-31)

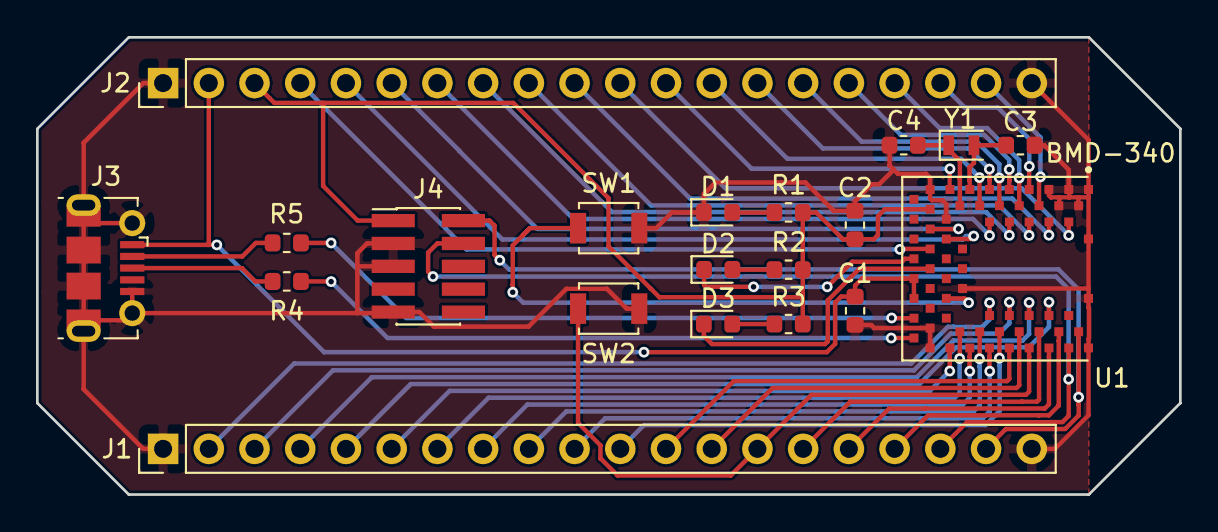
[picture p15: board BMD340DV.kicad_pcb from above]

Board: 2 copper layers, 63.5 x 25.4 mm, 20 parts (0 on the bottom side), 49 nets.

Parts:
C1: 4,7uF; C_0603_1608Metric
C2: 4.7uF; C_0603_1608Metric
C3, C4: 9pF; C_0603_1608Metric
D1, D2, D3: LED; LED_0603_1608Metric
J1, J2: Conn_01x20; PinHeader_1x20_P2.54mm_Vertical
J3: USB_B_Micro; USB_Micro-B_Molex-105017-0001
J4: Conn_02x05_Odd_Even; PinHeader_2x05_P1.27mm_Vertical_SMD
R1, R2, R3: 1k; R_0603_1608Metric
R4, R5: 27; R_0603_1608Metric
SW1, SW2: SW_Push; SW_SPST_B3U-1000P
U1: BMD-340; RIGADO_BMD-340-A-R
Y1: Crystal; Crystal_SMD_TXC_9HT11-2Pin_2.0x1.2mm

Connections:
/+: J3.3, R4.2
/-: J3.2, R5.2
/BUTTON1: SW1.1, U1.26
/D+: R4.1, U1.68
/D-: R5.1, U1.67
/LED1: D2.1, U1.64
/LED2: D3.1, U1.23
/P0.02: J2.12, U1.15
/P0.03: J2.6, U1.19
/P0.04: J2.5, U1.20
/P0.05: J2.4, U1.21
/P0.13: J1.6, U1.31
/P0.14: J1.7, U1.32
/P0.15: J1.8, U1.33
/P0.16: J1.9, U1.34
/P0.17: J1.10, U1.35
/P0.19: J1.12, U1.37
/P0.20: J1.13, U1.38
/P0.21: J1.11, U1.36
/P0.22: J1.15, U1.40
/P0.23: J1.16, U1.41
/P0.24: J1.17, U1.42
/P0.25: J2.19, U1.6
/P0.26: J2.18, U1.7
/P0.27: J2.17, U1.8
/P0.28: J2.16, U1.9
/P0.29: J2.15, U1.10
/P0.30: J2.14, U1.11
/P0.31: J2.13, U1.12
/P1.00: J1.2, U1.56
/P1.01: J1.3, U1.57
/P1.02: J1.4, U1.58
/P1.03: J1.5, U1.59
/P1.05: J2.11, U1.48
/P1.06: J2.10, U1.49
/P1.07: J2.9, U1.50
/P1.08: J2.8, U1.51
/P1.09: J2.7, U1.52
/RST: J1.14, SW2.2, U1.39
/SWCLK: J1.18, J4.4, U1.43
/SWDIO: J1.19, J4.2, U1.44
/VBUS: C1.2, J2.2, J3.1, U1.65, U1.66
/VCC: C2.1, J2.3, J4.1, R1.1, R2.1, R3.1, U1.17
GNDREF: C1.1, C2.2, C3.2, C4.2, D1.1, J1.1, J1.20, J2.1, J2.20, J3.5, J3.6, J4.3, J4.5, J4.9, SW1.2, SW2.1, U1.1, U1.2, U1.3, U1.4, U1.5, U1.16, U1.18, U1.29, U1.30, U1.45, U1.46, U1.47, U1.55
unnamed: C3.1, U1.13, Y1.2
unnamed: C4.1, U1.14, Y1.1
unnamed: D1.2, R1.2
unnamed: D2.2, R2.2
unnamed: D3.2, R3.2

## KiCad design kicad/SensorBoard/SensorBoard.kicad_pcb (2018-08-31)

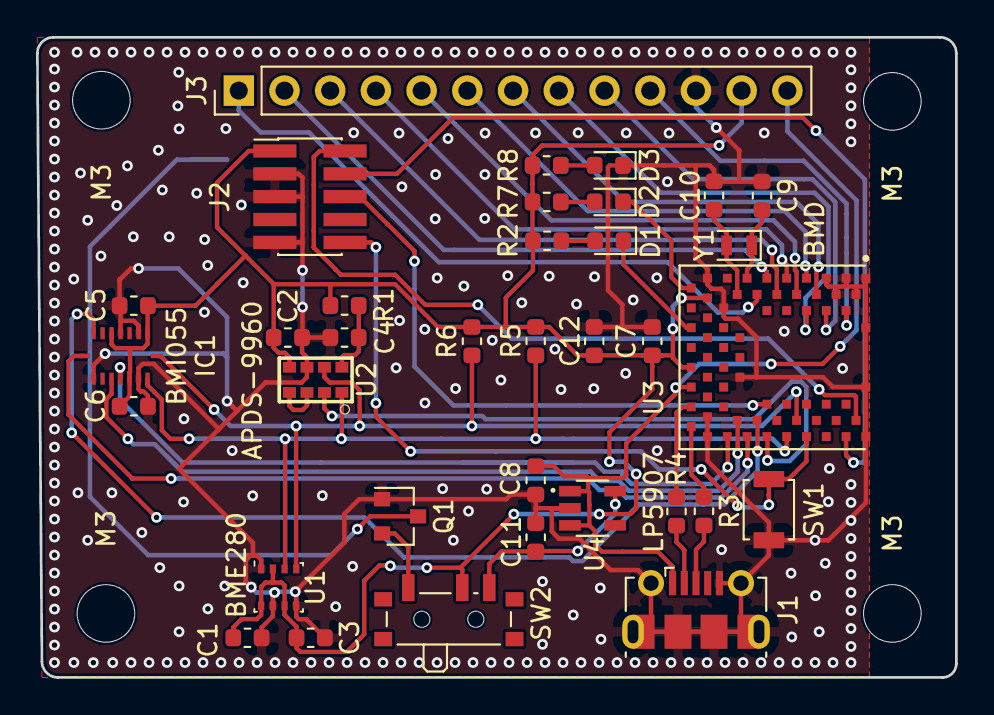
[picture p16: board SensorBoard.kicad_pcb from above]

Board: 2 copper layers, 51.1 x 35.6 mm, 40 parts (1 on the bottom side), 40 nets.

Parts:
BT1: Battery_Cell; BatteryHolder_Keystone_3034_1x20mm
C1, C2, C3, C4, C5, C6, C12: 100nF; C_0603_1608Metric
C7, C8: 4,7uF; C_0603_1608Metric
C9, C10: 12,5pF; C_0603_1608Metric
C11: 10uF; C_0603_1608Metric
D1, D2: LED; LED_0603_1608Metric
D3: LED POWER; LED_0603_1608Metric
IC1: BMI055; QFN50P300X450X100-16N
J1: USB_B_Micro; USB_Micro-B_Molex-105017-0001
J2: Conn_02x05_Odd_Even; PinHeader_2x05_P1.27mm_Vertical_SMD
J3: Conn_01x13; PinHeader_1x13_P2.54mm_Vertical
M3, M3#2, M3#3, M3#4: MountingHole_3.2mm_M3
Q1: TP0610T; SOT-23
R1: 22; R_0603_1608Metric
R2, R7, R8: 1k; R_0603_1608Metric
R3, R4: 27; R_0603_1608Metric
R5, R6: 4,7k; R_0603_1608Metric
SW1: SW_Push; SW_SPST_B3U-1000P
SW2: SW_SPDT; SW_SPDT_PCM12
U1: BME280; Bosch_LGA-8_2.5x2.5mm_P0.65mm_ClockwisePinNumbering
U2: APDS-9960
U3: BMD; RIGADO_BMD-340-A-R
U4: LP5907; SOT95P280X145-5N
Y1: 32.768KHz; Crystal_SMD_TXC_9HT11-2Pin_2.0x1.2mm

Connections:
/+: J1.3, R3.2
/-: J1.2, R4.2
/D+: R3.1, U3.68
/D-: R4.1, U3.67
/INT1A: IC1.16, U3.33
/INT1G: IC1.12, U3.31
/INT2A: IC1.1, U3.34
/INT2G: IC1.13, U3.32
/INTL: U2.2, U3.35
/LED1: D1.1, U3.63
/LED2: D2.1, U3.61
/P0.25: J3.7, U3.6
/P0.26: J3.6, U3.7
/P0.27: J3.5, U3.8
/P0.28: J3.4, U3.9
/P0.29: J3.3, U3.10
/P0.30: J3.2, U3.11
/P0.31: J3.1, U3.12
/P1.05: J3.10, U3.48
/P1.06: J3.9, U3.49
/P1.07: J3.8, U3.50
/RST: J2.10, SW1.1, U3.39
/SCL: IC1.8, R6.2, U1.4, U2.7, U3.38
/SDA: IC1.9, R5.2, U1.3, U2.1, U3.37
/SWCLK: J2.4, U3.43
/SWDIO: J2.2, U3.44
/SWO: J2.6, U3.56
/VBUS: C8.1, J1.1, J3.13, U3.66, U4.1, U4.3
/VCC: C1.1, C2.1, C3.1, C5.1, C6.1, C7.2, C12.1, IC1.3, IC1.7, IC1.11, J2.1, J3.12, R1.2, R2.1, R5.1, R6.1, R7.1, R8.1, SW2.2, U1.2, U1.6, U1.8, U2.5, U3.17, U3.65
/VCCB: Q1.2, SW2.1
/VCCR: C11.1, SW2.3, U4.5
/XTAL1: C9.2, U3.13, Y1.1
/XTAL2: C10.2, U3.14, Y1.2
GNDREF: BT1.2, C1.2, C2.2, C3.2, C4.2, C5.2, C6.2, C7.1, C8.2, C9.1, C10.1, C11.2, C12.2, D3.1, IC1.4, IC1.6, IC1.10, IC1.15, J1.5, J1.6, J2.3, J2.5, J2.9, J3.11, Q1.1, SW1.2, U1.1, U1.5, U1.7, U2.6, U3.1, U3.2, U3.3, U3.4, U3.5, U3.16, U3.18, U3.29, U3.30, U3.45, U3.46, U3.47, U3.55, U4.2
unnamed: BT1.1, Q1.3
unnamed: C4.1, R1.1, U2.8
unnamed: D1.2, R2.2
unnamed: D2.2, R7.2
unnamed: D3.2, R8.2
unnamed: U2.3, U2.4

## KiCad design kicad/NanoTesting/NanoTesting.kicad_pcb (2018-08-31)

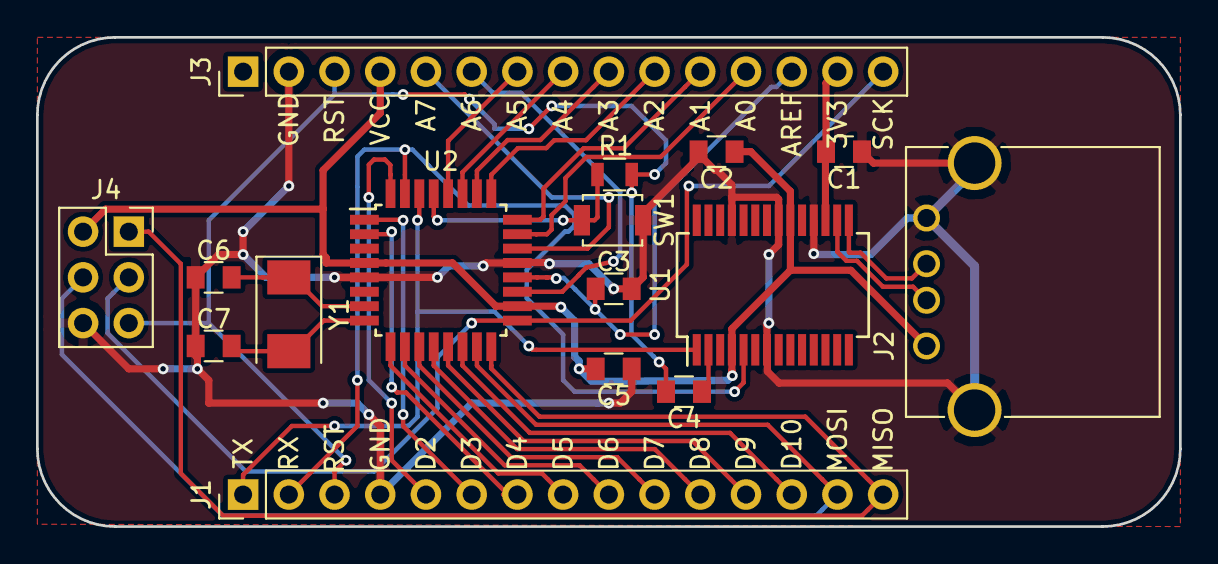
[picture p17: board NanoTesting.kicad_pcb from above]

Board: 2 copper layers, 63.5 x 27.2 mm, 16 parts (0 on the bottom side), 33 nets.

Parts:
C1, C2, C3, C4, C5: 100nF; C_0805
C6, C7: 18pF; C_0805
J1, J3: Conn_01x15; Socket_Strip_Straight_1x15_Pitch2.54mm
J2: USB_A
J4: Conn_02x03_Odd_Even; Socket_Strip_Straight_2x03_Pitch2.54mm
R1: 1K; R_0805
SW1: SW_Push; SW_SPST_B3U-1000P
U1: FT232RL; SSOP-28_5.3x10.2mm_Pitch0.65mm
U2: ATMEGA328PB-AU; TQFP-32_7x7mm_Pitch0.8mm
Y1: 16MHz; Crystal_SMD_Abracon_ABM3-2pin_5.0x3.2mm

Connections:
/3V3: C1.1, J3.14, U1.17
/A0: J3.12, U2.23
/A1: J3.11, U2.24
/A2: J3.10, U2.25
/A3: J3.9, U2.26
/A4: J3.8, U2.27
/A5: J3.7, U2.28
/A6: J3.6, U2.19
/A7: J3.5, U2.22
/AREF: C3.1, J3.13, U2.20
/D2: J1.5, U2.32
/D3: J1.6, U2.1
/D4: J1.7, U2.2
/D5: J1.8, U2.9
/D6: J1.9, U2.10
/D7: J1.10, U2.11
/D8: J1.11, U2.12
/D9: J1.12, U2.13
/D10: J1.13, U2.14
/DTR: C4.1, U1.2
/MISO: J1.15, J4.1, U2.16
/MOSI: J1.14, J4.4, U2.15
/RST: C4.2, J1.3, J3.3, J4.5, R1.1
/RX: J1.2, U1.5, U2.31
/SCK: J3.15, J4.3, U2.17
/TX: J1.1, U1.1, U2.30
/VCC: C2.2, C5.2, J2.1, J3.4, J4.2, U1.4, U1.20, U2.4, U2.18
/XTAL1: C6.2, U2.7, Y1.1
/XTAL2: C7.2, U2.8, Y1.2
GND: C1.2, C2.1, C3.2, C5.1, C6.1, C7.1, J1.4, J2.4, J2.5, J3.2, J4.6, SW1.2, U1.7, U1.18, U1.21, U1.25, U2.5, U2.21
unnamed: J2.2, U1.16
unnamed: J2.3, U1.15
unnamed: R1.2, SW1.1, U2.29

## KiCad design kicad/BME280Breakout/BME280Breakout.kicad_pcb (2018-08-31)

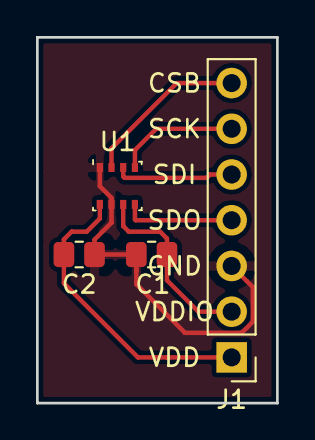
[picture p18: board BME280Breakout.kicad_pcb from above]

Board: 2 copper layers, 13.3 x 20.3 mm, 4 parts (0 on the bottom side), 7 nets.

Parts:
C1, C2: 100nF; C_0805_2012Metric
J1: Conn_01x07; PinHeader_1x07_P2.54mm_Vertical
U1: BME280; Bosch_LGA-8_2.5x2.5mm_P0.65mm_ClockwisePinNumbering

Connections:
/CSB: J1.7, U1.2
/SCK: J1.6, U1.4
/SDI: J1.5, U1.3
/SDO: J1.4, U1.5
/VDD: C2.2, J1.1, U1.8
/VDDIO: C1.2, J1.2, U1.6
GND: C1.1, C2.1, J1.3, U1.1, U1.7

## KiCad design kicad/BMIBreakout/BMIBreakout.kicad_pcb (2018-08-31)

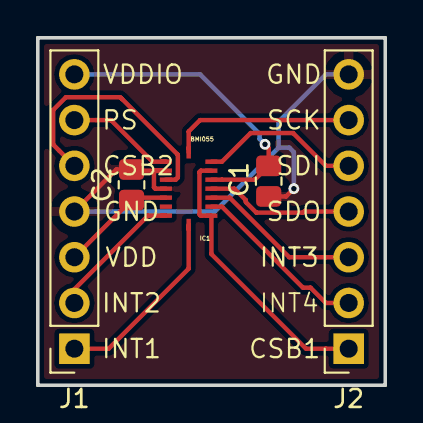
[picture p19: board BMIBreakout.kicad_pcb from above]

Board: 2 copper layers, 19.3 x 19.3 mm, 5 parts (0 on the bottom side), 13 nets.

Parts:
C1, C2: C; C_0805_2012Metric
IC1: BMI055; QFN50P300X450X100-16N
J1, J2: Conn_01x07; PinSocket_1x07_P2.54mm_Vertical

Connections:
/CSB1: IC1.14, J2.2
/CSB2: IC1.5, J1.5
/INT1: IC1.16, J1.1
/INT2: IC1.1, J1.2
/INT3: IC1.12, J2.4
/INT4: IC1.13, J2.3
/PS: IC1.7, J1.6
/SCK: IC1.8, J2.6
/SDI: IC1.9, J2.5
/SDO: IC1.10, IC1.15, J2.1
/VDD: C2.1, IC1.3, J1.3
/VDDIO: C1.1, IC1.11, J1.7
GND: C1.2, C2.2, IC1.4, IC1.6, J1.4, J2.7

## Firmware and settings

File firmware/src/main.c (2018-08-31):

/********************************************************
 *		This file and all its contents are				*
 *		licensed under the MIT v2.0 license.			*
 *		See LICENSE in the root folder for				*
 *		more information.								*														*
 ********************************************************/

/**
 * template.c
 *
 * Created: 2018-07-05
 * Last Modified: 2018-08_19
 * Author(s): Thao Nguyen
 **/

//#include "custom_board.h"
#include "boards.h"
#include "nrf_pwr_mgmt.h"

#include "nrf_log.h"
#include "nrf_log_ctrl.h"
#include "nrf_log_default_backends.h"

#include "advertising.h"
#include "sensors.h"	//sensors_init
#include "encrypt.h"	//crypt_init

#include "flash_fds.h"

volatile uint32_t ctr = 0;
uint8_t ctr_to_flash = 10;

/**@brief Function for initializing logging. */
static void log_init(void)
{
    ret_code_t err_code = NRF_LOG_INIT(NULL);
    APP_ERROR_CHECK(err_code);

    NRF_LOG_DEFAULT_BACKENDS_INIT();
}

/**@brief Function for initializing LEDs. */
static void leds_init(void)
{
	bsp_board_init(BSP_INIT_LEDS);
}

/**@brief Function for initializing power management.
 */
static void power_management_init(void)
{
    ret_code_t err_code;
    err_code = nrf_pwr_mgmt_init();
    APP_ERROR_CHECK(err_code);
}

/**@brief Function for handling the idle state (main loop).
 *
 * @details If there is no pending log operation, then sleep until next the next event occurs.
 */
static void idle_state_handle(void)
{
    if (NRF_LOG_PROCESS() == false)
    {
        nrf_pwr_mgmt_run();
        //bsp_board_led_on(BSP_BOARD_LED_0);
    }
}

/**@brief Function for initializing on startup.
 */
void initialize(void)
{
	leds_init();
    log_init();
    timers_init();
    power_management_init();
    ble_stack_init();
    advertising_init();
    radio_notification_init();
    sensors_init();
    crypt_init();
    NRF_LOG_FLUSH();
    flash_fds_init();
}

/***MAIN***/

/**@brief Function for application main entry.
 */
int main(void)
{
    // Initialize.
	initialize();
	// Check if counter exist in flash.
	update_ctr_in_flash(ctr_to_flash);
    // Start execution.
    NRF_LOG_INFO("Beacon started!");
    NRF_LOG_FLUSH();
    advertising_start();
    advdata_update_timer_start();


    // Enter main loop.
    while(true)
    {
        idle_state_handle();
    }
}

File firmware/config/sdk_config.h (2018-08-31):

/**
 * Copyright (c) 2017 - 2018, Nordic Semiconductor ASA
 * 
 * All rights reserved.
 * 
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
 * 3. Neither the name of Nordic Semiconductor ASA nor the names of its
 *    contributors may be used to endorse or promote products derived from this
 *    software without specific prior written permission.
 * 
 * 4. This software, with or without modification, must only be used with a
 *    Nordic Semiconductor ASA integrated circuit.
 * 
 * 5. Any software provided in binary form under this license must not be reverse
 *    engineered, decompiled, modified and/or disassembled.
 * 
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
 */



#ifndef SDK_CONFIG_H
#define SDK_CONFIG_H
// <<< Use Configuration Wizard in Context Menu >>>\n
#ifdef USE_APP_CONFIG
#include "app_config.h"
#endif
// <h> nRF_BLE 


// <o> PM_MAX_REGISTRANTS - Number of event handlers that can be registered. 
#ifndef PM_MAX_REGISTRANTS
#define PM_MAX_REGISTRANTS 3
#endif

// <o> PM_FLASH_BUFFERS - Number of internal buffers for flash operations. 
// <i> Decrease this value to lower RAM usage.

#ifndef PM_FLASH_BUFFERS
#define PM_FLASH_BUFFERS 2
#endif

// <q> PM_CENTRAL_ENABLED  - Enable/disable central-specific Peer Manager functionality.
 

// <i> Enable/disable central-specific Peer Manager functionality.

#ifndef PM_CENTRAL_ENABLED
#define PM_CENTRAL_ENABLED 1
#endif

// <q> PM_SERVICE_CHANGED_ENABLED  - Enable/disable the service changed management for GATT server in Peer Manager.
 

// <i> If not using a GATT server, or using a server wihout a service changed characteristic,
// <i> disable this to save code space.

#ifndef PM_SERVICE_CHANGED_ENABLED
#define PM_SERVICE_CHANGED_ENABLED 1
#endif

// <q> PM_PEER_RANKS_ENABLED  - Enable/disable the peer rank management in Peer Manager.
 

// <i> Set this to false to save code space if not using the peer rank API.

#ifndef PM_PEER_RANKS_ENABLED
#define PM_PEER_RANKS_ENABLED 1
#endif

// </e>


// <o> BLE_BAS_CONFIG_LOG_LEVEL  - Default Severity level
 
// <0=> Off 
// <1=> Error 
// <2=> Warning 
// <3=> Info 
// <4=> Debug 

#ifndef BLE_BAS_CONFIG_LOG_LEVEL
#define BLE_BAS_CONFIG_LOG_LEVEL 3
#endif

// <o> BLE_BAS_CONFIG_INFO_COLOR  - ANSI escape code prefix.
 
// <0=> Default 
// <1=> Black 
// <2=> Red 
// <3=> Green 
// <4=> Yellow 
// <5=> Blue 
// <6=> Magenta 
// <7=> Cyan 
// <8=> White 

// <o> BLE_IAS_CONFIG_LOG_LEVEL  - Default Severity level
 
// <0=> Off
// <1=> Error
// <2=> Warning
// <3=> Info
// <4=> Debug

#ifndef BLE_IAS_CONFIG_LOG_LEVEL
#define BLE_IAS_CONFIG_LOG_LEVEL 3
#endif

// <o> BLE_IAS_CONFIG_INFO_COLOR  - ANSI escape code prefix.
 
// <0=> Default 
// <1=> Black 
// <2=> Red 
// <3=> Green 
// <4=> Yellow 
// <5=> Blue 
// <6=> Magenta 
// <7=> Cyan 
// <8=> White 

#ifndef BLE_NUS_CONFIG_LOG_LEVEL
#define BLE_NUS_CONFIG_LOG_LEVEL 3
#endif

// <o> BLE_NUS_CONFIG_INFO_COLOR  - ANSI escape code prefix.
 
// <0=> Default 
// <1=> Black 
// <2=> Red 
// <3=> Green 
// <4=> Yellow 
// <5=> Blue 
// <6=> Magenta 
// <7=> Cyan 
// <8=> White 

// <o> NRF_STACK_GUARD_CONFIG_SIZE  - Size of stack guard
 
// <5=> 32 bytes 
// <6=> 64 bytes 
// <7=> 128 bytes 
// <8=> 256 bytes 
// <9=> 512 bytes 
// <10=> 1024 bytes 
// <11=> 2048 bytes 
// <12=> 4096 bytes 

#ifndef NRF_STACK_GUARD_CONFIG_SIZE
#define NRF_STACK_GUARD_CONFIG_SIZE 7
#endif

// </e>

// </h> 
//==========================================================

// <h> nRF_Crypto 

//==========================================================
// <e> NRF_CRYPTO_ENABLED - nrf_crypto - Cryptography library
//==========================================================
#ifndef NRF_CRYPTO_ENABLED
#define NRF_CRYPTO_ENABLED 1
#endif
// <o> NRF_CRYPTO_ALLOCATOR  - Memory allocator
 

// <i> Choose memory allocator used by nrf_crypto. Default is alloca if possible or nrf_malloc otherwise. If 'User macros' are selected then user have to create 'nrf_crypto_allocator.h' file containing NRF_CRYPTO_ALLOC, NRF_CRYPTO_FREE and NRF_CRYPTO_ALLOC_ON_STACK
// <0=> Default 
// <1=> User macros 
// <2=> On stack (alloca) 
// <3=> C dynamic memory (malloc) 
// <4=> SDK Memory Manager (nrf_malloc) 

// <q> NRF_CRYPTO_BACKEND_CC310_BL_ECC_SECP256R1_ENABLED  - Enable the secp256r1 elliptic curve support using CC310_BL.
 

#ifndef NRF_CRYPTO_BACKEND_CC310_BL_ECC_SECP256R1_ENABLED
#define NRF_CRYPTO_BACKEND_CC310_BL_ECC_SECP256R1_ENABLED 1
#endif

// <q> NRF_CRYPTO_BACKEND_CC310_BL_HASH_SHA256_ENABLED  - CC310_BL SHA-256 hash functionality.
 

// <i> CC310_BL backend implementation for hardware-accelerated SHA-256.

#ifndef NRF_CRYPTO_BACKEND_CC310_BL_HASH_SHA256_ENABLED
#define NRF_CRYPTO_BACKEND_CC310_BL_HASH_SHA256_ENABLED 1
#endif

// <q> NRF_CRYPTO_BACKEND_CC310_BL_HASH_LITTLE_ENDIAN_DIGEST_ENABLED  - nrf_cc310_bl hash outputs digests in little endian
 

// <o> NRF_CRYPTO_BACKEND_CC310_BL_HASH_AUTOMATIC_RAM_BUFFER_SIZE - nrf_cc310_bl hash outputs digests in little endian 
// <i> Makes the nrf_cc310_bl hash functions output digests in little endian format. Only for use in nRF SDK DFU!
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

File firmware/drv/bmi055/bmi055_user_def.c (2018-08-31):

/************************************************
 *	This file and all its contents are	*
 *	licensed under the MIT license.	*
 *	See LICENSE in the root folder for	*
 *	more information.			*
 ************************************************/

/**
 * template.c
 *
 * Created: 2018-07-31
 * Last Modified: 2018-08-21
 * Author(s): Thao Nguyen, Teemu Vierros
 **/


#include "nrf_log.h"
#include "nrf_log_ctrl.h"
#include "nrf_delay.h"

#include "sensors.h"	// sensor_t
#include "packing.h"	// to use htno functions

//#include "bma2x2_support.h"
//#include "bmg160_support.h"

#include "bma2x2.h"
#include "bmg160.h"
//#define BMG160_API
//#define BMA2x2_API
#define C_BMG160_TWO_U8X	2
#include "bma2x2_support.c"
#include "bmg160_support.c"



struct bmg160_t bmg160;
struct bmg160_data_t data_gyro;
struct bma2x2_t bma2x2;
struct bma2x2_accel_data sample_xyz;

extern sensor_t bmi055;

extern volatile type state;

s8 I2C_bus_write(u8 dev_addr, u8 reg_addr, u8 *reg_data, u8 cnt)
{
	s32 iError = BMG160_INIT_VALUE; //always success
	user_i2c_write( dev_addr, reg_addr, reg_data, cnt);
	return (s8)iError;
}
s8 I2C_bus_read(u8 dev_addr, u8 reg_addr, u8 *reg_data, u8 cnt)
{
	s32 iError = BMG160_INIT_VALUE; //always success
	user_i2c_read(dev_addr, reg_addr, reg_data, cnt);
	return (s8)iError;
}
void delay_msek(u32 msek)
{
	nrf_delay_ms(msek);
}
void bmi055_user_init(void)
{

			bmg160.bus_write = I2C_bus_write;
			bmg160.bus_read = I2C_bus_read;
			bmg160.delay_msec = delay_msek;
			bmg160.dev_addr = BMG160_I2C_ADDR1;

			if(bmg160_init(&bmg160)!=0){
				NRF_LOG_WARNING("BMI055(BMG160) initialization failed!");
			}else{
				bmg160_set_power_mode(BMG160_MODE_NORMAL);
				bmg160_set_bw(0x01);
				NRF_LOG_INFO("BMI055(BMG160) initialized!");
			}
		    NRF_LOG_FLUSH();

			bma2x2.bus_write = I2C_bus_write;
			bma2x2.bus_read = I2C_bus_read;
			bma2x2.delay_msec = delay_msek;
			bma2x2.dev_addr = BMA2x2_I2C_ADDR1;

			if(bma2x2_init(&bma2x2)!=0){
				NRF_LOG_WARNING("BMI055(BMA2x2) initialization failed!");
			}else{
				bma2x2_set_power_mode(BMA2x2_MODE_NORMAL);
				bma2x2_set_bw(0x08);
				NRF_LOG_INFO("BMI055(BMA2x2) initialized!");
			}
			NRF_LOG_FLUSH();
}

void bmi055_user_wake(void){
	bma2x2_set_power_mode(0);
	//nrf_delay_ms(30);
	//nrf_delay_ms(225);
}
void bmi055_user_sleep(void){
	bma2x2_set_power_mode(2);
	//nrf_delay_ms(30);
	//nrf_delay_ms(225);
}


void bmi055_user_read(void)
{
	//read GYRO

	uint8_t * pos = (uint8_t *) bmi055.p_data;
#define LONG	1
#if LONG
	uint16_t gyro[3] = {0};
	if(state == BMI_GYRO_TEMP){
		bmg160_get_data_XYZ(&data_gyro);

		gyro[0] = htno_16((uint16_t)data_gyro.datax);
		gyro[1] = htno_16((uint16_t)data_gyro.datay);
		gyro[2] = htno_16((uint16_t)data_gyro.dataz);

		NRF_LOG_INFO("bmi055 gyrox %d (0x%x)",(int16_t)data_gyro.datax,(int16_t)data_gyro.datax);
		NRF_LOG_INFO("bmi055 gyroy %d (0x%x)",(int16_t)data_gyro.datay,(int16_t)data_gyro.datay);
		NRF_LOG_INFO("bmi055 gyroz %d (0x%x)",(int16_t)data_gyro.dataz,(int16_t)data_gyro.dataz);
	}else{
		gyro[0] = 0;
		gyro[1] = 0;
		gyro[2] = 0;
	}
#else
	uint8_t gyro[3] = {0};
	if(state == BMI_GYRO_TEMP){
		bmg160_get_data_XYZ(&data_gyro);
		gyro[0] = (uint8_t)htno_16((uint16_t)data_gyro.datax);
		gyro[1] = (uint8_t)htno_16((uint16_t)data_gyro.datay);
		gyro[2] = (uint8_t)htno_16((uint16_t)data_gyro.dataz);
		NRF_LOG_INFO("bmi055 gyro: x = %d (0x%x), y = %d (0x%x), z = %d (0x%x)",(int8_t)gyro[0],gyro[0],(int8_t)gyro[1],gyro[1],(int8_t)gyro[2],gyro[2]);
	}else{
		gyro[0] = 0;
		gyro[1] = 0;
		gyro[2] = 0;
	}
#endif

	memcpy(pos,&gyro,sizeof(gyro));
	pos += sizeof(gyro);

	//read ACCELERATION

#if LONG
	uint16_t accel[3] = {0};
	if(state == BMI_ACCEL_APDS_PG){
		bma2x2_read_accel_xyz(&sample_xyz);
		accel[0] = htno_16((uint16_t)sample_xyz.x);
		accel[1] = htno_16((uint16_t)sample_xyz.y);
		accel[2] = htno_16((uint16_t)sample_xyz.z);

		NRF_LOG_INFO("bmi055 accelx %d (0x%x)",(int16_t)sample_xyz.x,(int16_t)sample_xyz.x);
		NRF_LOG_INFO("bmi055 accely %d (0x%x)",(int16_t)sample_xyz.y,(int16_t)sample_xyz.y);
		NRF_LOG_INFO("bmi055 accelz %d (0x%x)",(int16_t)sample_xyz.z,(int16_t)sample_xyz.z);
	}else{
		accel[0] = 0;
		accel[1] = 0;
		accel[2] = 0;
	}
#else
	uint8_t accel[3] = {0};
	if(state == BMI_ACCEL_APDS_PG){
		bma2x2_read_accel_xyz(&sample_xyz);
		accel[0] = (uint8_t)htno_16((uint16_t)sample_xyz.x);
		accel[1] = (uint8_t)htno_16((uint16_t)sample_xyz.y);
		accel[2] = (uint8_t)htno_16((uint16_t)sample_xyz.z);
		NRF_LOG_INFO("bmi055 accel: x = %d (0x%x), y = %d (0x%x), z = %d (0x%x)",(int8_t)accel[0],accel[0],(int8_t)accel[1],accel[1],(int8_t)accel[2],accel[2]);
	}else{
		accel[0] = 0;
		accel[1] = 0;
		accel[2] = 0;
	}
	#endif

	memcpy(pos,&accel,sizeof(accel));
	pos += sizeof(accel);

}

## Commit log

2018-08-31 Project submission.
    [BMD340DV.kicad_pcb, BMD340DV.sch, BME280Breakout.kicad_pcb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]
2018-09-02 Small fix to simulated device. Example device config added.
